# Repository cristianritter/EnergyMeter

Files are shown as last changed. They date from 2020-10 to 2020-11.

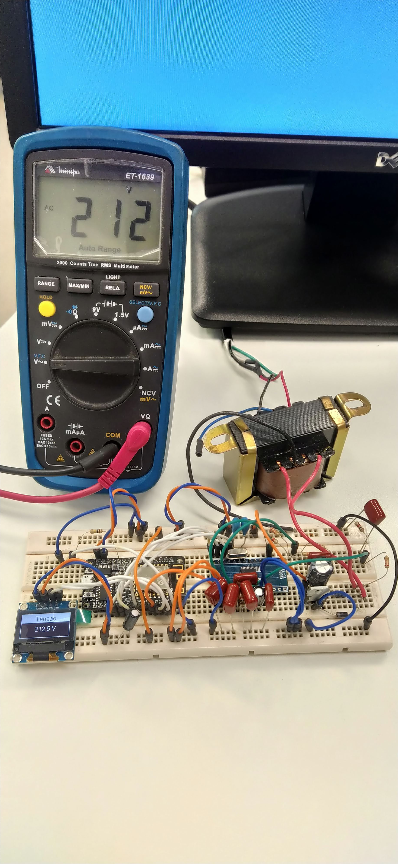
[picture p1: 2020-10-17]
DOCS/Medicoes/IMG_20200415_161844.jpg

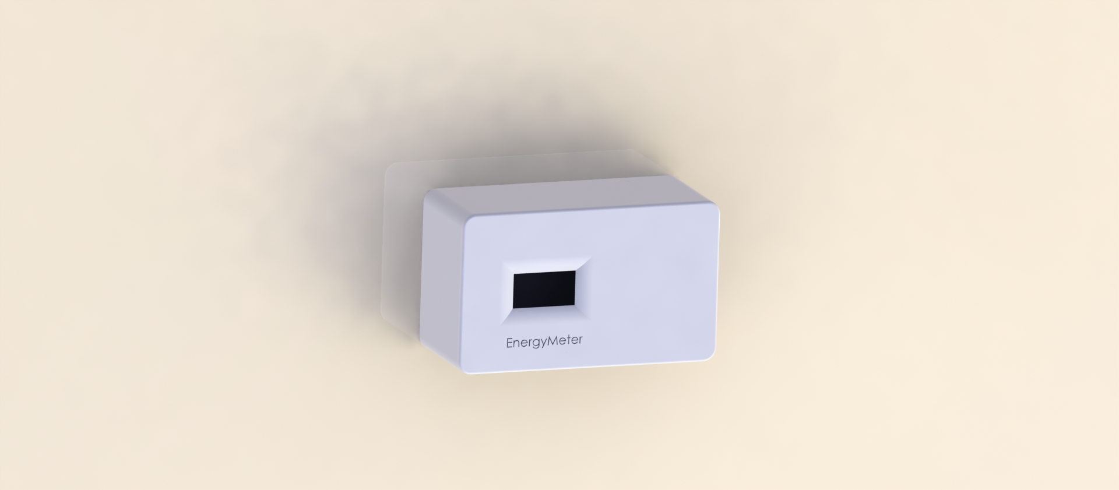
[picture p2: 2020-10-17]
DOCS/Ilustracoes/product_render.JPG

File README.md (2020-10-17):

# EnergyMeter

##### Este trabalho foi desenvolvido por Cristian Fernando Ritter para apresentação como Trabalho de Conclusão do curso de Engenharia Mecatrônica do IFSC.

O código do repositório foi embarcado em uma ESP8266 e possui um hardware externo de diversos componentes que executam as demais funções eletrônicas do conjunto.
Mais informações sobre o projeto podem ser encontradas na pasta DOCS.

>**Documentação disponível:**

| Pasta | Informações |
|---|---|
| DOCS  | Documentação do trabalho, artigos relacionados, datasheets e outras informações relevantes |
| ESP8266  | Código desenvolvido para o microcontrolador |
| Projeto  | Arquivos do projeto da placa de circuito impresso (Proteus) e dos invólucros (SolidWorks) |
| ServidorWeb  | Código da página web de consulta |

**Links Úteis**:

[Video da apresentação do TCC](https://drive.google.com/file/d/1ILbdENN5ZJW_IXzVvyy8BjTQIgMoMRp9/view?usp=sharing)

[Continuação do desenvolvimento com MariaDb e Mosquitto Broker rodando em uma rasp](https://github.com/cristianritter/ENERGY_METER_MOSQUITTO)

-----------
Este trabalho foi encerrado e a continuação do desenvolvimento está disponível no [link](https://github.com/cristianritter/ENERGY_METER_MOSQUITTO).

Florianópolis, Outubro de 2020.

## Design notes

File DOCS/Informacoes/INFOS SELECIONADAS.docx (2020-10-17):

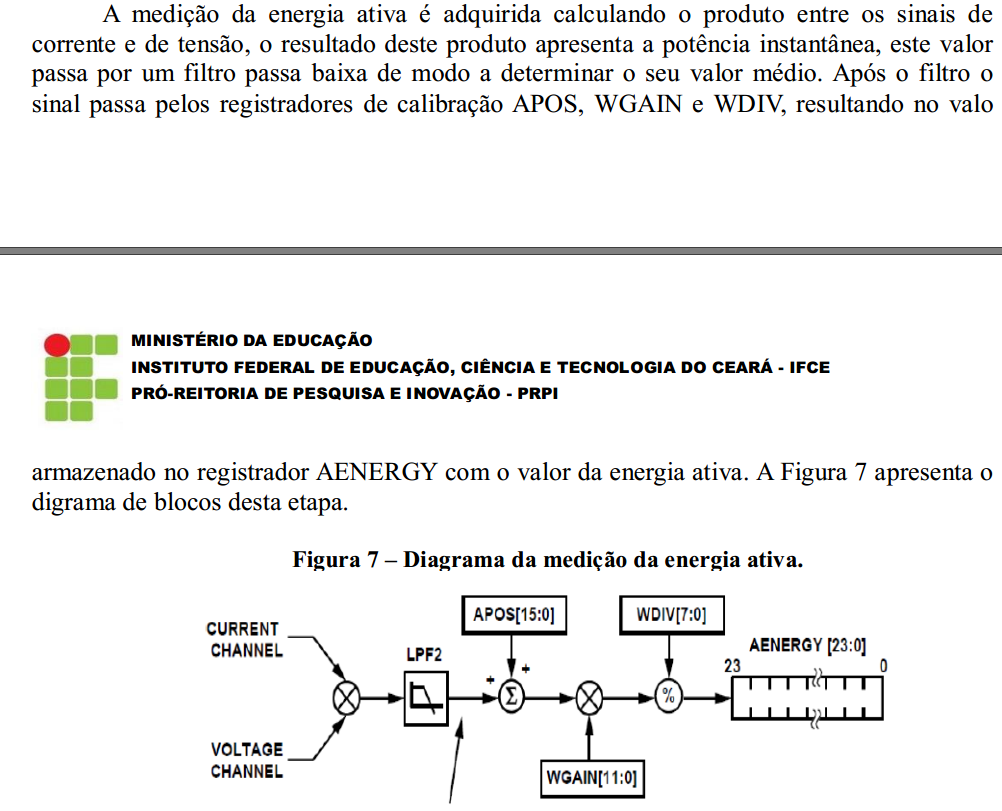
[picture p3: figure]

6. REFERÊNCIAS
ANEEL – Agência Nacional de Energia Elétrica. Informações técnicas: Tarifas,
consumidores Finais. Disponível em: <http://www.aneel.gov.br/area.cfm?idArea=91 >.
Acesso em: 07 mar. 2014.
ALEXANDER, C. K.; SADIKU, M. N. O. Fundamentos de circuitos elétricos. Porto
Alegre: Bookman, 2003.
ANALOG DEVICES, ADE7753 Data Sheet: Single-Phase Multifunction Metering IC
with di/dt Sensor Interface. 2017. Disponível em:
<http://www.analog.com/media/en/technical-documentation/data-sheets/ADE7753.pdf>.
Acesso em: 31 mar. 2017.
MINISTÉRIO DA EDUCAÇÃO
INSTITUTO FEDERAL DE EDUCAÇÃO, CIÊNCIA E TECNOLOGIA DO CEARÁ - IFCE
PRÓ-REITORIA DE PESQUISA E INOVAÇÃO - PRPI
BEN – Balanço Energético Nacional. Síntese do relatório final. Ano base: 2012. Rio de
janeiro: EPE, 2013.
BOYLESTAD, Robert L. Introdução à análise de circuitos. 12. ed. São Paulo: Pearson
Prentice Hall, 2012.
LEÃO, Ruth; Sampaio, Raimundo; ANTUNES, Fernando. Harmônicos em sistemas
elétricos. 1. Ed. Rio de Janeiro: Ed. Elsevier, 2014.
LEM. LV20-P Data Sheet: Voltage Transducer. 2005. Disponível em:
<http://media.digikey.com/pdf/Data%20Sheets/LEM%20USA%20PDFs/LV%2020-P.pdf>.
Acesso em: 03 mar. 2017.
______. LA55-P Data Sheet: Current Transducer. 2009. Disponível em:
<http://www.lem.com/docs/products/la%2055-p%20e.pdf>. Acesso em: 03 mar. 2017.
MARKUS, O. Circuitos elétricos: Corrente contínua e corrente alternada teoria e
exercícios. 9 ed. São Paulo: Érica, 2011.
NATIONAL INSTRUMENTS. O que é o LabView?. 2014. Disponível em:
<http://www.ni.com/newsletter/51141/pt/>. Acesso em: 31 mar. 2017.
POPSIN, J. Desenvolvimento de um analisador e medidor monofásico de energia.
Trabalho de conclusão de curso (Bacharel em Engenharia Elétrica), Universidade Luterana
do Brasil, Canoas - RS, 2010.

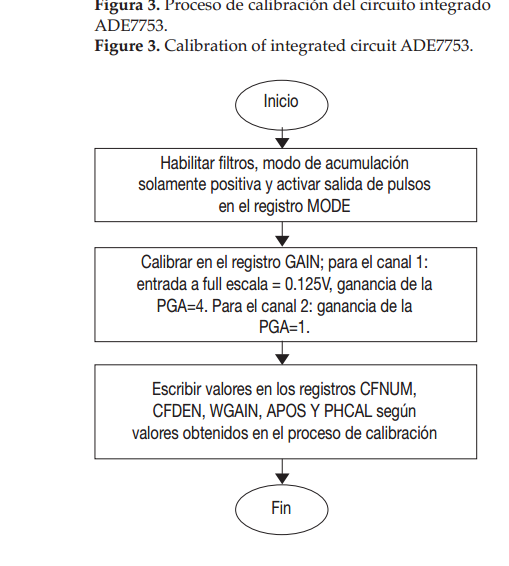
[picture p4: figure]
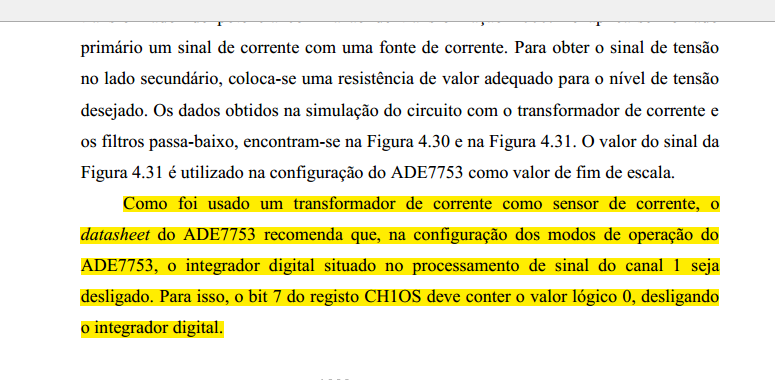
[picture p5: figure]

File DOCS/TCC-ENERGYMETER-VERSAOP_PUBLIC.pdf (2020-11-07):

CAMPUS FLORIANÓPOLIS

DEPARTAMENTO ACADÊMICO DE METAL-MECÂNICA

BACHARELADO EM ENGENHARIA MECATRÔNICA

CRISTIAN FERNANDO RITTER

## MEDIDOR DE ENERGIA MONOFÁSICO DE BAIXA TENSÃO

## BASEADO EM REDES SEM FIO

FLORIANÓPOLIS, OUTUBRO DE 2020

INSTITUTO FEDERAL DE EDUCAÇÃO, CIÊNCIA E TECNOLOGIA DE SANTA CATARINA

CAMPUS FLORIANÓPOLIS

DEPARTAMENTO ACADÊMICO DE METAL-MECÂNICA

BACHARELADO EM ENGENHARIA MECATRÔNICA

CRISTIAN FERNANDO RITTER

## MEDIDOR DE ENERGIA MONOFÁSICO DE BAIXA

## TENSÃO BASEADO EM REDES SEM FIO

FLORIANÓPOLIS, OUTUBRO DE 2020

Trabalho de Conclusão de Curso de Graduação,

apresentado à disciplina de Trabalho de Conclusão

de Curso, do curso de Engenharia Mecatrônica, do

Departamento Acadêmico de Metal-Mecânica, do

Instituto | Federal | de | Educação, | Ciência | e

Tecnologia de Santa Catarina, como requisito

parcial à obtenção do título de Bacharel em

Engenharia Mecatrônica.

Orientador Prof. Valdir Noll, Dr. Eng.

Ficha de identificação da obra elaborada pelo autor.

Ritter, Cristian Fernando
Medidor de Energia Monofásico de Baixa Tensão Baseado em Redes Sem Fio / Cristian Fernando Ritter ; orientação de Valdir Noll.
- Florianópolis, SC, 2020

86 p.

Trabalho de Conclusão de Curso (TCC) – Instituto Federal de Santa Catarina, Campus Florianópolis. Bacharelado em Engenharia Mecatrônica, Departamento Acadêmico de Metal Mecânica.

Inclui Referências.

1. | Internet | das | Coisas. | 2. | Monitor | de | Energia. | 3.
Microcontroladores. | I. | Noll, | Valdir. | II. | Instituto
Federal | de | Santa | Catarina. | Departamento | Acadêmico | de
Metal Mecânica. III. Título

MEDIDOR DE ENERGIA MONOFÁSICO DE BAIXA TENSÃO BASEADO EM REDES SEM

FIO

CRISTIAN FERNANDO RITTER

Este trabalho foi julgado adequado para obtenção de título de Bacharel em Engenharia

Mecatrônica e aprovado na sua forma final pela banca examinadora do Curso de Bacharelado em

Engenharia Mecatrônica do Instituto Federal de Educação, Ciência e Tecnologia de Santa Catarina.

Florianópolis, 16 de outubro de 2020.

Banca examinadora:

____________________________________

Prof. Valdir Noll, Dr.

Orientador

____________________________________

Prof. Gregory Chagas da Costa Gomes

Membro Titular

____________________________________

Prof. Mario de Noronha Neto, Dr.

Membro Titular

## RESUMO

RITTER, Cristian Fernando. MEDIDOR DE ENERGIA MONOFÁSICO DE BAIXA

TENSÃO BASEADO EM REDES SEM FIO. 85 f. Trabalho de Conclusão de Curso

(Graduação) – Curso de Engenharia Mecatrônica, Instituto Federal de Educação, Ciência e

Tecnologia de Santa Catarina. Florianópolis, 2020.

Neste trabalho propõe-se o desenvolvimento de um sistema para medição de energia

monofásico de baixa tensão baseado em redes de comunicação de dados sem fio que

realizará o monitoramento de diversos parâmetros elétricos da rede e seu registro em um

serviço de banco de dados. O sistema será desenvolvido em um microcontrolador que

enviará os dados para um serviço de Internet das Coisas. Uma interface web permitirá a

filtragem e consulta dos dados de qualquer lugar por meio de um acesso à internet. O banco

de informações adquirido poderá ser usado para inúmeros fins, que incluem: traçar um

padrão de consumo do local, definir estatisticamente a estimativa do consumo, verificar

informações relacionadas à conformidade do fornecimento de energia elétrica e possíveis

problemas na instalação elétrica, como desperdício de energia ou problemas no coeficiente

de fator de potência. Além disso, este sistema pode colaborar na realização de mudanças

nos hábitos de consumo que permitam aprimorar a eficiência energética do ambiente

monitorado.

Palavras chave: Internet das Coisas, monitor de energia, microcontroladores, sensores

de corrente e tensão.

## ABSTRACT

RITTER, Cristian Fernando. LOW-VOLTAGE SINGLE-PHASE POWER METER BASED

ON WIRELESS NETWORKS. 85 f. Trabalho de Conclusão de Curso (Graduação) – Curso de

Engenharia Mecatrônica, Instituto Federal de Educação, Ciência e Tecnologia de Santa

Catarina. Florianópolis, 2020.

This work proposes the development of a measuring single-phase low voltage energy

system based on a wireless network that will monitor several electrical grid parameters and

record them in a database service. This system will be developed in a microcontroller that will

use Internet of Things data. Web interface will allow filtering and querying data from anywhere

that has internet access. Collected database can be used for a number of purposes, which

include: drawing a consumption pattern, prediction, information related to the conformity of

the electricity and to investigate electrical installation troubles, such as waste of electricity and

problems with the power factor coefficient. In addition, this system can collaborate to make

changes in consumption habits allowing energy efficiency improvements.

Keywords: Internet of Things, energy monitor, microcontrollers, current and voltage

sensors.

## LISTA DE FIGURAS

Figura 18 – Diagrama de utilização de transformadores de corrente. Fonte: Analog Devices

Todas as figuras que não possuem fontes informadas são de autoria própria.

## LISTA DE EQUAÇÕES

## LISTA DE SIGLAS

ADC | Analogic to digital converter (conversor analógico-digital)
ABESCO | Associação Brasileira das Empresas de Serviços de Conservação de Energia
AC | Alternate Current (corrente alternada)
AGND | Analogic Ground (ground do circuito analógico)
AP | Access Point (ponto de acesso à rede sem fio)
AVDD | Tensão de alimentação positiva do circuito analógico
AWS | Amazon Web Services
CSS | Cascading Style Sheets
CT | Current Transformer (transformador de corrente)
DC | Direct Current (corrente continua)
DGND | Digital Ground (ground do circuito digital)
DVDD | Tensão de alimentação positiva do circuito digital
EC2 | Elastic Compute Cloud
GND | Ground
GPIO | General Purpose Input/Output
HTML | Hyper Text Markup Language
I2C | Inter-Integrated Circuit
IDE | Integrated Development Environment
IOT | Internet of things (internet das coisas)
JSON | Java Script Object Notation
LSB | Least Significant Bit (bit menos significativo)
MQTT | MQ Telemetry Transport
MSB | Most Significant Bit (bit mais significativo)
PHP | Hypertext Preprocessor
PWM | Pulse-Width Modulation
RMS | Root mean square

SLA | Service Level Agreement (termos do acordo de serviço)
SPI | Serial Peripheral Interface
TCP/IP | Internet protocol suite
UTC | Coordinated Universal Time
UTS | Unix Time Stamp

## SUMÁRIO

## 1 INTRODUÇÃO

Concorrentemente à popularização da internet e sua disponibilização sobre diversas

formas de propagação, muitas delas sem a necessidade de fios, houve também a ampliação

da gama de dispositivos com dimensões reduzidas e baixo consumo que podem acessar tais

redes e compartilhar dados de sensoriamento e até mesmo de controle para sistemas nas

mais diversas áreas, com uma ótima relação de custo benefício. Isso tem incentivado uma

cada vez mais evidente tendência de interconexão e monitoração de dispositivos e

ambientes, não somente industriais, mas também domésticos.

Diante da necessidade de coleta e análise de grandes quantidades de dados, surgiram

diversas empresas que oferecem serviços de tratamento e armazenamento de dados em

servidores remotos. Tais serviços dispensam a necessidade de quaisquer servidores ou

infraestrutura hospedada localmente para manter um serviço disponível online.

Dispondo do recente amadurecimento das tecnologias citadas acima, propõe-se neste

trabalho o desenvolvimento de um sistema para medição de energia monofásica de baixa

tensão baseado em rede sem fio que realizará o monitoramento e registro de diversos

parâmetros elétricos da rede. A medição dos parâmetros elétricos da rede será feita

utilizando um circuito integrado especificamente desenvolvido para este fim. Utilizar-se-á um

microcontrolador com interface de rede sem fio integrada para leitura, processamento e envio

de informações que serão armazenados em um serviço de armazenamento de dados online.

As análises e os resultados obtidos poderão ser consultados diretamente pela internet em

uma aplicação web desenvolvida para este fim.

Os dados obtidos poderão ser utilizados para diversos fins, como por exemplo, definir

estatisticamente a previsibilidade do consumo, verificar informações relacionadas à

conformidade do fornecimento de energia elétrica e possíveis mudanças nos hábitos de

consumo que permitam aprimorar a eficiência energética do ambiente monitorado.

### 1.1 OBJETIVOS

### 1.1.1 OBJETIVO GERAL

Desenvolvimento de um sistema que permita monitorar a qualidade de fornecimento e o

consumo de energia elétrica de uma residência ou outro ambiente. O sistema permitirá a

visualização dos dados em uma interface com gráficos de consumo em retrospecção, além

de análises baseadas nos hábitos de consumo registrados.

Os principais requisitos de projeto são:

- O hardware de aquisição dos dados deve ser compacto.
- O produto deve oferecer segurança ao usuário e fácil instalação.
- O custo do produto final deve ser um dos itens a ser considerado na escolha

dos componentes eletrônicos.

- O acesso do usuário à interface de consulta dos dados e resultados deve ser

feita de maneira simples e prática por meio de uma interface de aplicativo ou página

da web na internet.

- O dispositivo de medição deve ser capaz de enviar os dados para o banco de

dados por meio de redes sem fio.

- O acesso aos dados deve estar protegido de acessos indevidos por meio de

autenticação de usuário e senha ou outra tecnologia similar.

### 1.1.2 OBJETIVOS ESPECIFICOS

Para facilitar a organização deste trabalho e tentar garantir que todos os requisitos

citados no objetivo principal sejam atingidos com sucesso, foram elaborados objetivos

específicos que servirão como metas sequenciais a serem alcançadas durante o

desenvolvimento. Como itens de uma lista inicial de objetivos específicos podem ser

alistados:

- Descrição em esboço de funcionamento do sistema.
- Análise dos fluxos de dados e de viabilidade técnica e econômica.
- Pesquisa e definição das tecnologias e componentes a serem utilizadas.
- Estudo e descrição de todas as tecnologias e componentes envolvidos no

projeto.

- Elaboração dos diagramas elétricos e eletrônicos.

- Programação dos dispositivos eletrônicos e das plataformas de back-end.
- Execução de testes e correções.
- Programação das plataformas de front-end.
- Montagem de protótipo.
- Testes, correções e aprimoramentos finais.
- Apresentação dos resultados.

### 1.2 JUSTIFICATIVA

A utilização racional de energia é um ponto de pauta importante à medida que o mundo

procura pensar e agir de modo sustentável. Conforme relatório divulgado pela Associação

Brasileira das Empresas de Serviços de Conservação de Energia (ABESCO) e noticiado pelo

jornal O Estadão, o desperdício de energia custou mais de R$60 bilhões para a economia

brasileira nos anos de 2015 a 2017. Além do prejuízo econômico, o uso indiscriminado da

energia aumenta a geração de gases nocivos para a atmosfera, sendo responsável por uma

parcela no efeito.

No Brasil, a maior parte da geração de energia elétrica provém de usinas hidrelétricas,

ficando, portanto suscetíveis a mudanças climáticas e a períodos de estiagens, bem como

afeta o ambiente quando se necessita ampliar a produção, pois exigem grandes áreas

territoriais. Diante da ocorrência de longos períodos sem chuvas, outras formas de geração

de energia podem ser utilizadas, porém muitas delas geram maior poluição e possuem maior

custo por kWh gerado.

Para tentar analisar e corrigir os hábitos de consumo precisa-se mensurar

adequadamente o consumo de energia de modo adequado. Neste aspecto, o medidor de

energia elétrica da concessionária de energia não se mostra eficiente, pois não permite a

visualização remota nem a criação de um banco de dados retrospectivo de consumo, além

de não diferenciar os dados de cada ambiente.

A proposta deste trabalho é desenvolver um sistema capaz de facilitar a medição da

energia elétrica em residências ou ambientes similares, permitindo que sejam coletados

dados zoneados do consumo. Este sistema será capaz de informar quanto cada

equipamento está consumindo, e em quais horários.

Com um mapa de consumo completo do ambiente podem ser tomadas medidas

assertivas com o objetivo de substituir equipamentos de baixa eficiência energética e

identificar gargalos de consumo. Ampliando-se a utilização de um sistema como esse a nível

nacional, certamente poderiam ser minimizados o desperdício de energia e a necessidade de

constantes investimentos em infraestrutura de geração e distribuição de energia, além de

colaborar para um melhor uso dos recursos naturais.

### 1.3 METODOLOGIA

Conforme descrito nos objetivos, este projeto é um dispositivo de ‘Internet das Coisas’ e

utiliza plataformas de serviços disponibilizados online para evitar a necessidade de hospedar

servidores localmente. O sistema é formado por diversos serviços trabalhando em conjunto,

sendo cada um responsável por tarefas especificas.

Seu desenvolvimento tem caráter experimental, contemplando o projeto de um protótipo

de dispositivo para medição e a programação dos firmwares e códigos fontes das aplicações

necessárias. Além disso, será necessária a configuração de diversos serviços para a

integração dos componentes em nuvem computacional. O estudo necessário para o

desenvolvimento de tais atividades será realizado com base na documentação

disponibilizada pelos serviços web, documentações de bibliotecas, bem como também, na

informação presente nos manuais de componentes e em experiências de autores que

desenvolveram trabalhos semelhantes anteriormente.

Com a finalidade de facilitar o entendimento ao expor a integração esperada entre os

sistemas que serão desenvolvidos, será apresentado um esboço geral do sistema proposto.

### 1.3.1 ESBOÇO GERAL DO SISTEMA

A Figura 1 ilustra o relacionamento entre o conjunto dos serviços de computação em

nuvem, dos dispositivos de aquisição de dados e da interface com o usuário.

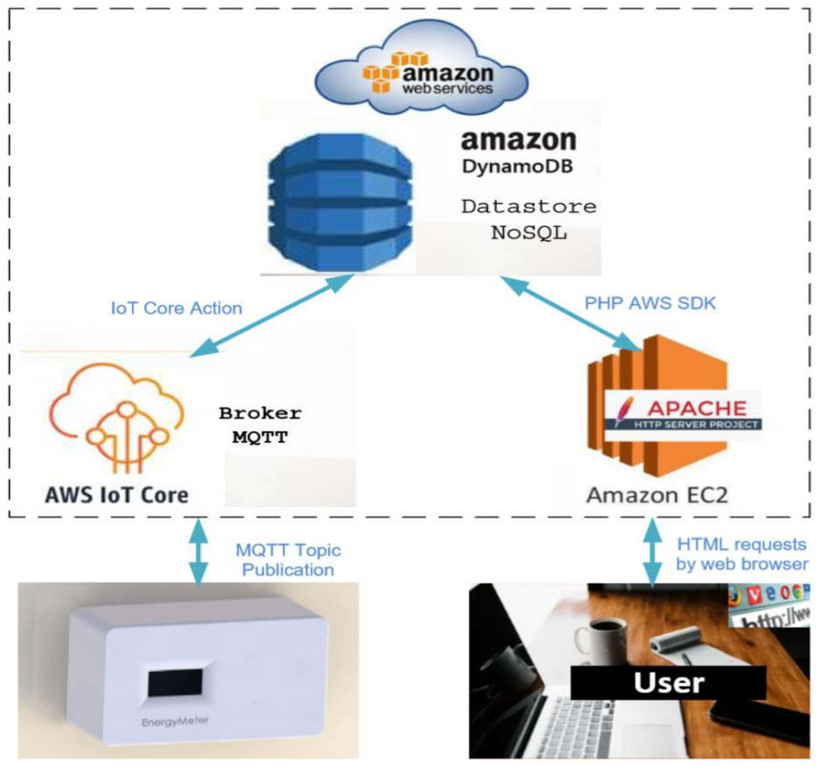
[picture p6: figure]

Figura 1 - Esboço geral do sistema.

Será produzido um protótipo de dispositivo eletrônico medidor de energia chamado de

Energy Meter, que executará o envio das informações adquiridas para um broker que

interpretará os dados e armazenará em um banco de dados online. Estes dados podem ser

consultados por meio de requisições realizadas de uma página web especificamente

desenvolvida para este fim que será disponibilizada por um serviço de hospedagem.

### 1.4 ESTRUTURA DO DOCUMENTO

A documentação deste projeto está dividida em capítulos para facilitar a organização,

sendo: Introdução, Fundamentação teórica, Desenvolvimento, Resultados e Conclusão.

Na Introdução estão contidas diversas informações iniciais, que incluem considerações

sobre o tema e o trabalho proposto. Nesta seção são definidos também os requisitos de

projeto, os objetivos e as razões que justificam o seu desenvolvimento.

A fundamentação teórica apresenta o estudo do conhecimento de base necessário para

a execução deste trabalho, com informações sobre todos os componentes, tecnologias,

linguagens de programação e formatos de dados utilizados. Todas as funcionalidades relevantes das plataformas serão explicadas, assim como seu funcionamento no presente

projeto. O embasamento do estudo das grandezas físicas mensuradas também estará

descrito nesta seção.

No Desenvolvimento estão descritas as razões que influenciaram a escolha dos

serviços e componentes escolhidos, e apresentados o circuito eletrônico e seu

funcionamento. São descritos os principais trechos de programação e as principais funções.

Na seção de Resultados apresentam-se um resumo e análises dos dados coletados

durantes os testes do protótipo produzido. Finalizando este capítulo são apresentadas as

principais dificuldades encontradas durante o desenvolvimento do trabalho.

A Conclusão apresenta observações relacionadas às expectativas com este projeto,

comentários oportunos sobre os objetivos que foram alcançados e sugestões de

aprimoramentos e desenvolvimentos para outros trabalhos.

## 2 FUNDAMENTAÇÃO TEÓRICA

### 2.1 SENSORES DE CORRENTE E TENSÃO

Serão utilizados sensores de tensão e corrente para a leitura dos parâmetros da rede.

O circuito integrado ADE7753 nos permite a utilização de diversos tipos de sensores.

Precisamos entender então a diferença entre eles para a seleção do sensor e sua correta

utilização.

### 2.1.1 SHUNTS RESISTIVOS

É composto basicamente por um resistor de baixo valor em série com a carga,

dimensionado de maneira que a queda de tensão seja bem pequena. Partindo-se do

princípio de que a queda de tensão é proporcional a corrente, pode-se mensurar a corrente

utilizando este tipo de sensor.

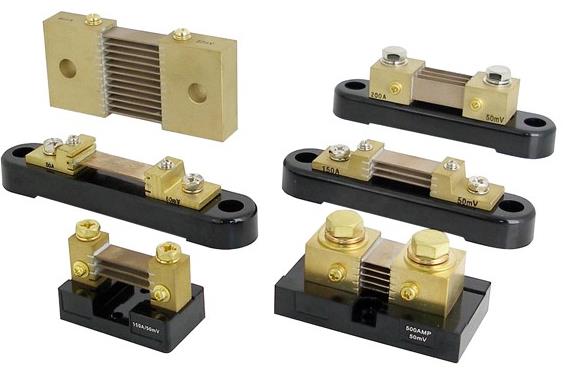
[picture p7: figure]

Figura 2 - Shunts resistivos. Fonte: AMDS4 (2020)

### 2.1.2 TRANSDUTORES DE EFEITO HALL

São dispositivos capazes de medir o fluxo de corrente com total isolamento galvânico,

isto é, sem a necessidade de inserir o dispositivo em série no circuito a ser medido. Podem

trabalhar com vários tipos de forma de onda e em uma ampla faixa de frequência. Possuem

uma saída em corrente determinada através de uma relação entrada / saída e possuem um

resistor de saída para transformar a saída de corrente em um valor de tensão. Pode-se

trabalhar com correntes alternadas ou contínuas, mas necessita de fonte de alimentação

auxiliar para o circuito hall.

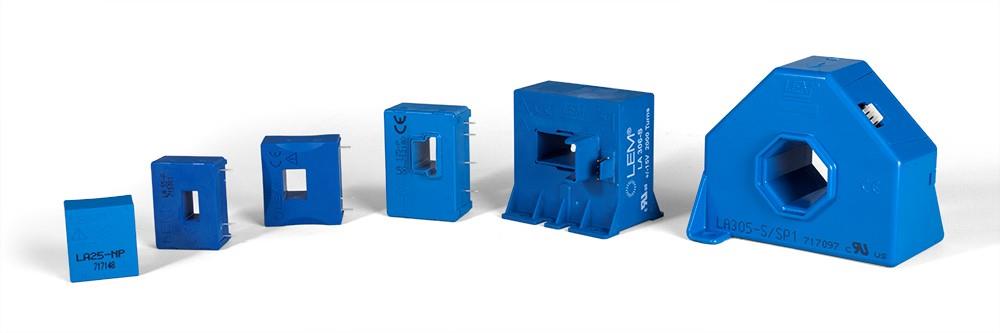
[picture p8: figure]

Figura 3 - Transdutores de Efeito Hall. Fonte: AMDS4 (2020)

### 2.1.3 TRANSFORMADOR DE CORRENTE

Um transformador de corrente [1] (conhecido como CT (Current Transformer)) é um

dispositivo que reproduz no seu circuito secundário, a corrente que circula em um

enrolamento primário com sua posição vetorial substancialmente mantida, em uma proporção definida, conhecida e adequada. É de baixo custo e serve apenas para correntes

alternadas.

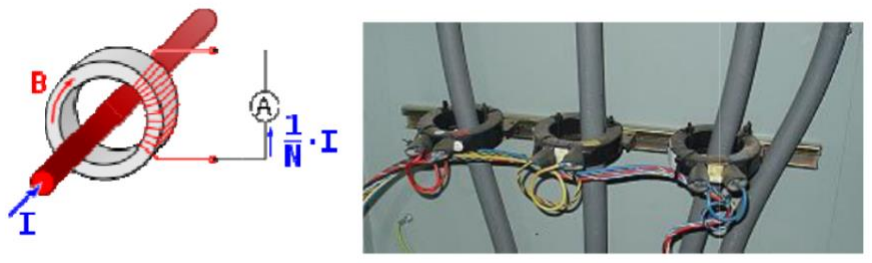
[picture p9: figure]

Figura 4 - Transformadores de Corrente. Fonte: AMDS4 (2020)

### 2.1.4 BOBINA DE ROGOWSKI

Na sua forma mais simples, a bobina de Rogowski é um sensor de corrente composto

por uma bobina enrolada uniformemente com muitas (N) voltas por metro em um núcleo não

magnético de área transversal constante. Por não possuir núcleo magnético, possui baixa

inércia eletromagnética, permitindo assim a medição de altas frequências com bastante

precisão. Serve apenas para correntes alternadas (AC).

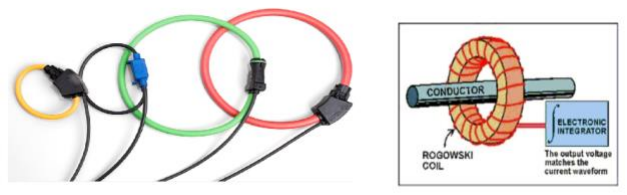
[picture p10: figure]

Figura 5 - Bobinas de Rogowski. Fonte: AMDS4 (2020)

### 2.1.5 ISOLAMENTO GALVÂNICO

Segundo a fornecedora YANASHI o isolamento galvânico em transdutores se faz

necessário quando se deseja que duas grandezas elétricas associadas fiquem separadas

eletricamente com o objetivo de atenuar interferências que possam causar danos ou

distúrbios aos circuitos ligados na saída do transdutor isolador. O isolamento colabora com a

segurança do circuito em casos de tensões altas, permitindo que a leitura do valor de

sensoriamento possa ser feita em uma tensão menor respeitando uma razão conhecida.

### 2.1.6 TRANFORMADOR E DIVISOR DE TENSÃO

Para o sensoriamento de tensões é comumente utilizado um circuito rebaixador

composto de dois resistores em série com uma derivação central. Através da relação entre a

resistência dos componentes utilizados obtêm-se uma amostra conhecida do valor de tensão

de entrada. Pode-se utilizar em conjunto com este circuito um transformador de tensão com

fator de redução conhecido para prover o isolamento elétrico.

### 2.2 CIRCUITO INTEGRADO ADE 7753

Este circuito integrado [6] mostrado na Figura 7 é um medidor que permite executar a

medição instantânea de potência ativa, reativa, e aparente em circuitos monofásicos de baixa

tensão. Permite também monitorar valores RMS de tensão e corrente, frequência, e de

eventos específicos como quedas de tensão e índices de fator de potência.

Figura 6 - Circuito integrado ADE7753. Fonte: Analog Devices (2010)

### 2.3 MÓDULO NODE MCU

O módulo de hardware conhecido como NodeMCU [3][4] é uma plataforma de

desenvolvimento que permite a prototipagem de projetos IOT. Os softwares utilizados são de código aberto (open source) e utilizam o microcontrolador Espressif ESP8266®
que integra

serviços de GPIO, PWM, I

2C e conversores A/D além de possuir também um módulo de

rede sem fio integrado que permite acesso à internet.

A parcela de serviços que será executada localmente está sob a responsabilidade

deste dispositivo. O módulo NodeMCU coletará as informações de energia dos registradores

do circuito integrado ADE7753 que está conectado aos sensores. Os dados adquiridos são

processados e publicados como uma mensagem JSON em um tópico MQTT previamente

definido.

Figura 7 - Módulo Node MCU com ESP8266. Fonte: FilipeFlop (2020)

### 2.4 PROTOCOLOS DE COMUNICAÇÃO E NOTAÇÃO

### 2.4.1 A INTERNET DAS COISAS E O PROTOCOLO MQTT

O protocolo MQTT é um protocolo com baixo payload (leve) de mensagens TCP/IP

para sensores ou dispositivos móveis. Este protocolo utiliza um esquema de comunicação

fundamentado no modelo publicador-assinante e é muito utilizado em internet das coisas.

Seu fundamento básico é apresentado na Figura 8.

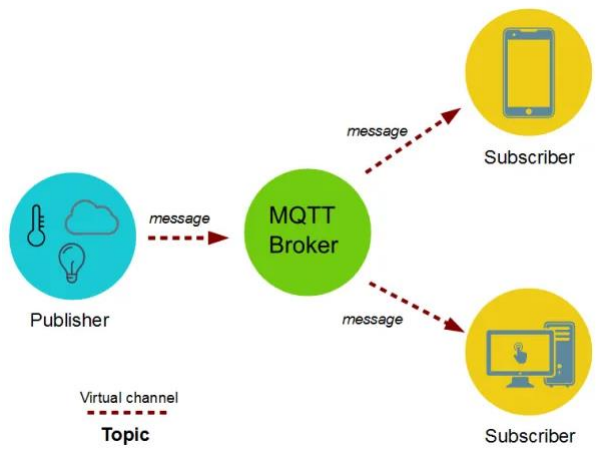
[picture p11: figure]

Figura 8 - Funcionamento do protocolo MQTT. Fonte: Ayush Gemini (2019)

São criados canais de comunicação virtuais chamados tópicos. Serviços e dispositivos

podem assinar ou publicar em um tópico de um broker específico. O tópico não faz parte da

mensagem, é apenas uma referência a um identificador de destino. Um dispositivo publica

em um tópico, e o broker MQTT realiza o envio da mensagem recebida a todos os

assinantes daquele tópico especifico.

A comunicação entre o dispositivo e o broker depende do serviço utilizado. Neste

trabalho utilizou-se o AWS IOT Core que se baseia em TCP/IP e transmite através da

internet executando autenticação de segurança por meio do uso de certificados.

### 2.4.2 SERIAL PERIPHERAL INTERFACE (SPI)

Este protocolo permite a comunicação do microcontrolador com diversos outros componentes, formando uma rede. É uma especificação de interface de comunicação série

síncrona usada para comunicação de curta distância, principalmente em sistemas

embarcados. No caso deste projeto a comunicação SPI permite que o modulo NodeMCU

execute a leitura e escrita dos registradores do circuito integrado ADE7743.

### 2.4.3 NOTAÇÃO JSON

Utilizaremos também um protocolo de notação muito comum para padronizar o

transporte de dados entre os serviços. O Java Script Object Notation (JSON) é um modelo de

formatação leve para troca de dados baseado em um subconjunto da linguagem de

programação Java Script e utiliza convenções familiares às linguagens C, Java, Java Script,

Perl, Python e muitas outras. Este modelo é constituído basicamente de uma coleção de

pares chave/valor. Em várias linguagens, isto é caracterizado como um dicionário ou matriz.

Estas são estruturas de dados universais e praticamente todas as linguagens de

programação modernas as suportam, sendo interessante que um formato de troca de dados

que seja independente de linguagem de programação se baseie nesse tipo de estrutura. A

Figura 9 apresenta um exemplo de pacote de dados JSON.

Figura 9 - Exemplo de pacote de dados JSON

### 2.5 AMAZON WEB SERVICES

A plataforma de serviços computacionais online Amazon Web Services (AWS) está

entre uma das mais adotadas e abrangentes do mundo, oferecendo mais de 175 serviços

disponíveis em qualquer lugar com acesso à internet. Milhões de clientes, incluindo

empresas de crescimento rápido (startups), grandes empresas e os maiores órgãos

governamentais, estão usando a AWS para reduzirem seus custos, ficarem mais ágeis e

inovarem seus processos mais rapidamente.

Neste projeto utilizam-se três serviços: o banco de dados Dynamo DB, o núcleo de

serviços de internet das coisas IOT Core e o serviço de computação em nuvem EC2.

Um guia explicativo sobre a configuração dos serviços AWS utilizados está disponível

no Apêndice B.

### 2.5.1 AWS IOT CORE

É um módulo da AWS que fornece serviços de IOT para soluções industriais,

comerciais e de consumo. O módulo AWS IOT Core permite que dispositivos conectados

interajam de maneira fácil e segura com aplicativos de nuvem e outros dispositivos.

Este serviço serve como um broker MQTT disponibilizando um canal de comunicação

entre o dispositivo e a nuvem computacional, permitindo a publicação em um tópico

específico, sendo assim responsável por receber as mensagens publicadas e retransmiti-las

a todos os clientes.

Neste projeto o tópico utilizado foi definido como: ‘aws/rules/Energy_meter’. A Figura 10

apresenta o formato da mensagem publicada.

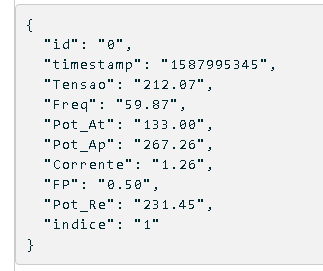
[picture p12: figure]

Figura 10 – Publicação de mensagem no tópico

A informação útil (payload) é uma matriz em um formato JSON. Os dados estão

organizados por chave e valor, permitindo que a mensagem seja interpretada pelo serviço

IOT Core. Pode-se configurar uma ação para que o próprio broker realize a interpretação dos

dados de cada mensagem e encaminhe o conteúdo para o banco de dados Dynamo DB.

Para que isso funcione deve-se certificar de que todas as colunas descritas nas chaves

existam de maneira idêntica no banco de dados Dynamo DB.

### 2.5.2 DYNAMO DB

É um serviço de banco de dados do tipo valor-chave que oferece ótimo desempenho e

confiabilidade dos dados armazenados. [9] Permite acesso aos dados por meio de diversas

linguagens computacionais, que incluem as mais utilizadas como Python, PHP e Java Script.

[10]

Neste projeto utiliza-se esta plataforma para armazenar as informações coletadas pelo

dispositivo de medição. Após a recepção de uma mensagem MQTT, seu conteúdo é

adicionado ao banco de dados pelo serviço IOT Core.

A Figura 8 mostra o formato de armazenamento de uma tabela do Dynamo DB. A

primeira linha define as chaves e as demais linhas representam os registros de valores.

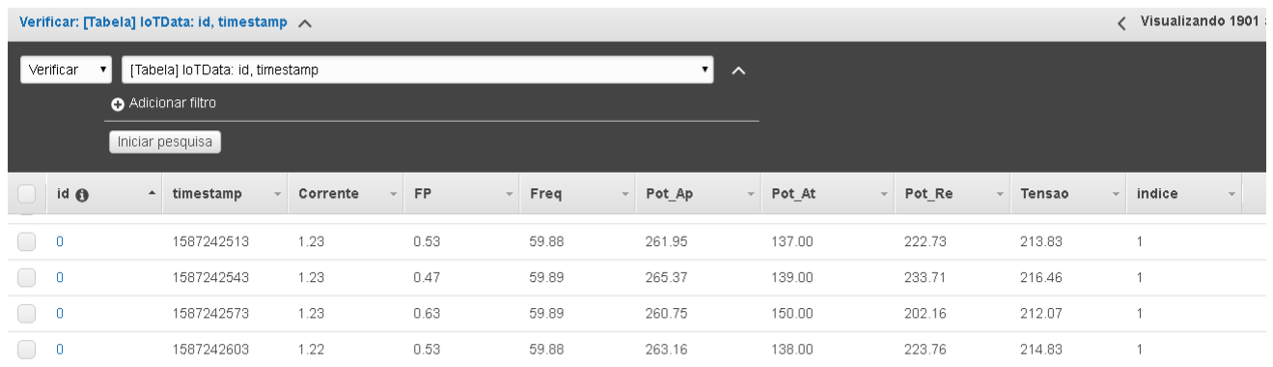
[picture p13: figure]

Figura 11 - Exemplo de tabela do Dynamo DB

Cada registro é formado por um conjunto de chaves e valores, sendo uma chave de

identificação do dispositivo, uma chave de classificação do registro e as demais chaves

relacionam os dados adquiridos. A chave id é chamada de chave de partição. A chave

timestamp, é uma chave de classificação e torna cada registro de dados único, por isso não

pode haver repetições dos valores desta chave. Isso é garantido pelo fato de que o valor de

timestamp é gerado no momento do envio do payload por um código UTS que corresponde à

quantidade de segundos desde o início do primeiro dia de janeiro 1970, no formato UTC +0.

### 2.5.3 AMAZON EC2

É um serviço que disponibiliza capacidade computacional segura e redimensionável na

nuvem computacional. Permite que seja configurado um sistema operacional em uma

máquina virtual e que serviços rodando nessa instancia sejam acessados remotamente de qualquer local. É possível liberar portas e acessos conforme a necessidade.

Utiliza-se esta plataforma para hospedar a aplicação desenvolvida, que será gerenciada

por um servidor Apache. Este servidor será responsável por responder a todas as

solicitações HTTP de consulta de dados. Far-se-á uso de uma instância executando o

sistema operacional Ubuntu Server e um servidor Apache. O acesso será realizado por meio

do endereço de DNS público da instancia EC2 por um navegador, tal como o Chrome.

### 2.5.4 PACOTE XAMPP

Adicionalmente aos serviços da Amazon, utiliza-se um pacote de softwares de uso livre

chamado XAMPP. Esta solução é uma distribuição Apache fácil de instalar e utilizar que contém os serviços de interpretação PHP, MySQL e Perl. É de uso livre, inclusive para fins

comerciais. Este serviço ficará hospedado em um servidor na nuvem e armazenará as

páginas web e os scripts PHP relacionados à consulta dos dados. Os demais serviços do

pacote não serão utilizados.

### 2.6 GRANDEZAS ELÉTRICAS

Para que possamos trabalhar corretamente com os sensores a serem utilizados,

precisamos entender os fundamentos relacionados às grandezas mensuradas. Neste projeto

usar-se-á a medição de sete grandezas diferentes, são elas: tensão, frequência, corrente,

potência ativa, potência reativa, potência aparente e fator de potência.

Grandezas como tensão, frequência, e corrente são corriqueiras e seus métodos de

medição bem compreendidos. O circuito integrado ADE7753 usado realiza a medição da

tensão por meio de um canal de entrada que mensura uma fração conhecida da tensão

amostrada. Posteriormente são realizados diversos cálculos para obtenção do valor real. A

frequência é obtida através da medição do período da onda amostrada, sabendo-se que a

frequência é o inverso do período da onda, pode-se calcular facilmente seu valor. A medição

de corrente neste caso será realizada por meio de um transformador de corrente, com

resistor de amostragem que transforma níveis de corrente dentro de um range específico em

níveis de tensão conhecidos com resposta linearizada, permitindo assim a medição de

corrente com uma exatidão aceitável.

### 2.6.1 POTÊNCIA APARENTE

É a soma vetorial das potências ativa e reativa. É medida em VA. Por meio desta

relação é extraído o valor do fator de potência de consumo da rede, que se resume ao

ângulo entre os catetos formados pelas potencias ativa e reativa. Este parâmetro da rede é

muito importante, pois está relacionado à eficiência do consumo excessivamente capacitivo

ou indutivo que, em alguns casos, pode ser mensurada e taxada pela empresa de

fornecimento de energia. Neste projeto o valor da potência aparente foi calculado por meio

da Equação 1.

S = VRMS.IRMS

Equação 1 - Potência aparente

### 2.6.2 FATOR DE POTÊNCIA

O fator de potência (FP) é uma relação entre a energia ativa e a energia aparente do

circuito em um determinado período de tempo. No ADE7753 temos dois registradores que

integram e armazenam cada um desses tipos de energia. Com duas amostras de períodos

distintos podemos calcular o FP. Se utilizássemos um período de 1 segundo entre a coleta

das amostras teríamos o apresentado na Equação 2. Este é o método utilizado para a

obtenção do fator de potência neste trabalho.

FP =

(EP1 − EP0

)

ES1 − Es0

=

P
S

Equação 2 - Fator de potência

### 2.6.3 POTENCIA ATIVA

A potência ativa instantânea é definida como a taxa de energia fluindo de uma fonte de alimentação para a carga a cada instante de tempo. É obtida pelo produto dos valores

instantâneos de tensão, corrente e fator de potência. A unidade de medida da potência ativa

é o Watt e equivale a um joule/segundo. A potência ativa está relacionada à realização de

trabalho como, por exemplo, geração de calor, movimento ou luz. A potência ativa é

calculada por meio da Equação 3.

P = V. I. cos θ = V. I. FP

Equação 3 - Potência ativa

### 2.6.4 POTÊNCIA REATIVA

É a energia utilizada que é responsável por manter o campo eletromagnético em

motores, geradores, transformadores e certos tipos de lâmpadas. Este tipo de energia não

gera trabalho, mas tem seu estudo relevante, pois afeta a carga das redes elétricas,

especialmente em grandes potências. Sua unidade de medida é o VAr. Neste trabalho seu

valor será obtido por meio da Equação 4.

Q = V.I. sen θ = V.I. sen(arc cos(FP))

Equação 4 - Potência reativa

## 3 DESENVOLVIMENTO

### 3.1 ELABORAÇÃO DO PROTÓTIPO

Para validar o projeto, o circuito eletrônico foi montado em uma placa de montagem

conforme mostra a Figura 12.

Figura 12 - Protótipo em placa de montagem

### 3.2 DESENVOLVIMENTO DA APLICAÇÃO WEB

Conforme as informações apresentadas na metodologia, os aspectos necessários de

configuração dos serviços WEB foram executados a contento. Os serviços da AWS foram

configurados e testados, a página web para interface com o usuário foi desenvolvida e

testada. A máquina virtual foi preparada, o servidor Apache instalado e os arquivos da

aplicação web carregados. Os procedimentos de configuração da AWS estão descritos no

apêndice B deste trabalho.

A aplicação web é composta de duas páginas: uma tela de autenticação, que é

apresentada na | Figura 13, e uma tela de dados, mostrada na | Figura 14.

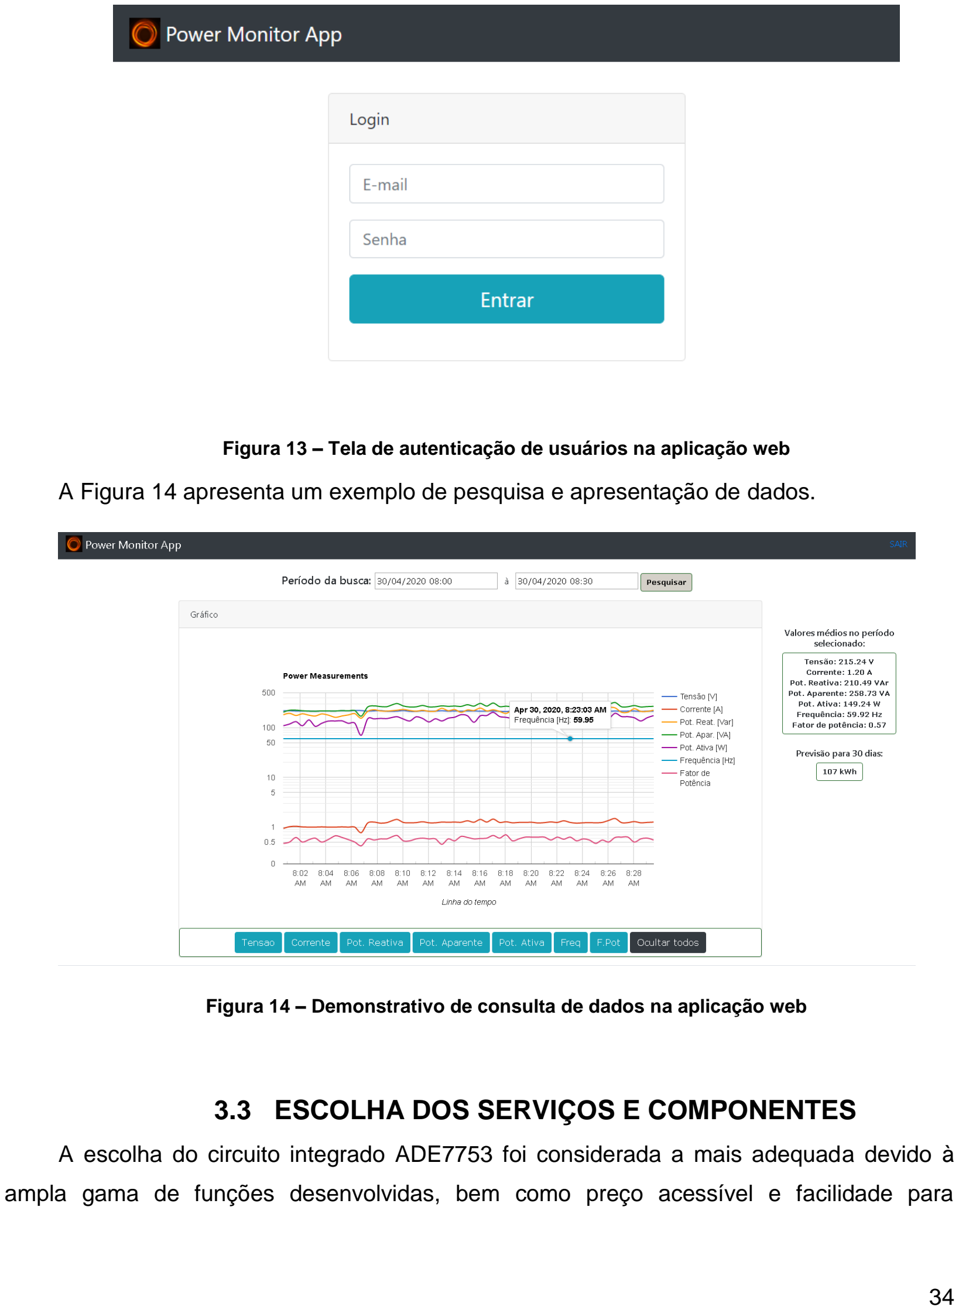
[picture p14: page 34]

Figura 13 – Tela de autenticação de usuários na aplicação web

A Figura 14 apresenta um exemplo de pesquisa e apresentação de dados.

Figura 14 – Demonstrativo de consulta de dados na aplicação web

### 3.3 ESCOLHA DOS SERVIÇOS E COMPONENTES

A escolha do circuito integrado ADE7753 foi considerada a mais adequada devido à

ampla gama de funções desenvolvidas, bem como preço acessível e facilidade para aquisição no mercado. Existem também, diversos trabalhos que utilizam este chip,

fornecendo uma ampla diversidade de materiais para consulta.

O microcontrolador ESP8266 foi escolhido para uso neste projeto pelo baixo custo e

adequação as necessidades do projeto. Seu tamanho físico reduzido com acesso à rede sem

fio incluído o tornam uma boa escolha para utilização em projetos de IOT.

A escolha da plataforma de serviços da Amazon foi uma escolha da equipe de projeto.

Existem diversos trabalhos que utilizam outras plataformas, principalmente com servidores

hospedados localmente, como por exemplo, utilizando o Mosquitto MQTT Broker e a SQL

database. Os serviços da AWS se encaixaram neste projeto, pois ainda não existem muitos

trabalhos acadêmicos que façam uso desta plataforma, além de ser um serviço comercial

cujo aprendizado pode ser útil posteriormente. A configuração dos serviços desta plataforma

não é de trivial aprendizado, mas está muito bem documentada. Além da documentação do

fabricante, existem também tutoriais em vídeos na plataforma Youtube que também auxiliam

no aprendizado desta plataforma. Todos os materiais utilizados estão alistados na bibliografia

deste trabalho.

O modelo de sistema apresentado com todos os serviços hospedados em servidores de

terceiros, possui diversas vantagens, como por exemplo, não existe a necessidade de dar

manutenções regulares, nem ter uma equipe local de suporte, diminuindo as despesas com

esses aspectos. A confiabilidade do serviço é aprimorada, sendo que a AWS promete uma

disponibilidade SLA (Service Level Agreement) de 99,99% no serviço de cloud computing. As

despesas por estes serviços são fixas e definidas pelas cotas de uso. Apesar disso,

dependendo da aplicação, pode ser vantajoso manter um serviço hospedado localmente, que

não dependa de serviços web contratados. Atualmente o valor de um contrato simples de computação em nuvem com a AWS está custando aproximadamente $100 por mês. Então

se não necessitamos de tanta confiabilidade quanto é oferecida pela AWS, pode ser

vantajoso testar provedores mais baratos deste serviço.

Trazendo a atenção para as linguagens de programação utilizadas, foram escolhidas

linguagens que estão sendo muito usadas no mercado. A programação da ESP8266 foi

desenvolvida em C, sendo a linguagem de mais baixo nível que compõe este trabalho. Todas

as demais estão relacionadas à programação web, que podem englobar muitas linguagens

em um mesmo sistema. A página web criada neste projeto utilizou trechos de código em

HTML, PHP, CSS e Java Script, além de utilizar pacotes de terceiros, como por exemplo, o

BOOTSTRAP que traz recursos de design importantes para a plataforma web. Várias

empresas disponibilizam | SDKs (Software development kit). | para utilização dos

desenvolvedores e isto é muito útil, pois permite que trechos de códigos já prontos sejam

reutilizados, facilitando o desenvolvimento. [18]

### 3.4 CIRCUITO ELETRÔNICO

Na Figura 15 é apresentado o circuito eletrônico do dispositivo proposto. O arranjo dos

componentes foi elaborado através das sugestões dadas pelo fabricante no manual do

componente.

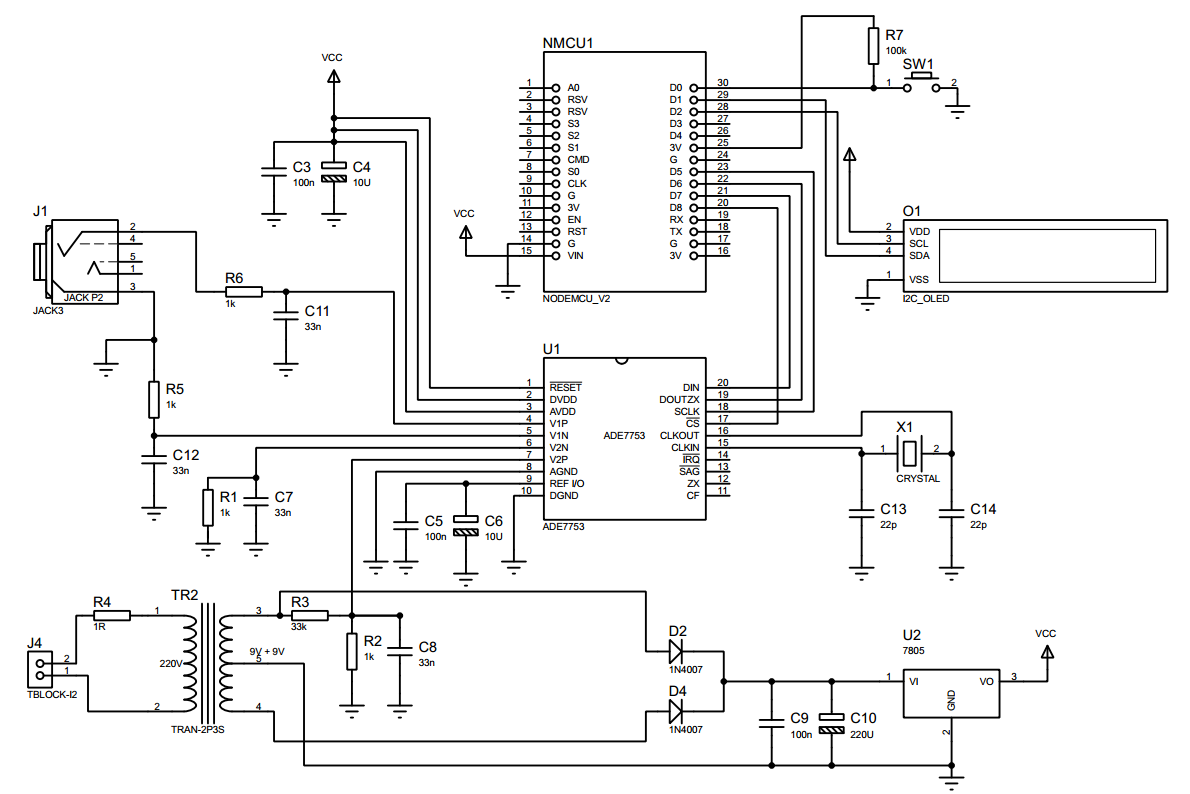
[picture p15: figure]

Figura 15 - Diagrama do circuito elétrico

O funcionamento deste circuito está construído sobre dois pilares principais. O primeiro

pilar está no circuito integrado ADE7753, que é um medidor de energia monofásico da

Analog Devices. O segundo pilar é composto pelo microcontrolador ESP8266 que faz parte

do módulo NodeMCU.

O circuito integrado executa todas as tarefas relacionadas à interpretação dos valores

retornados pelos sensores que a ele estão conectados, extraindo os valores desejados de

potências, tensão, corrente, entre outros. Todos estes valores estão armazenados em

registradores que podem ser lidos por meio do protocolo de comunicação SPI. Nos próximos

itens descreve-se em detalhes cada um desses pilares.

### 3.4.1 MEDIÇÃO DE ENERGIA COM O ADE7753

As conexões elétricas deste circuito integrado foram executadas conforme instruções

do fabricante presentes no datasheet do produto. A seguir então descritas às informações

sobre os principais pinos utilizados e suas funções especificas:

a) Os primeiro três pinos são respectivamente o pino de reset, a alimentação positiva

do circuito digital (DVDD) e a alimentação positiva do circuito analógico (AVDD).

Sendo o reset ativo em nível lógico baixo, manteremos estes três pinos conectados

ao VCC.

b) Pinos 8 e 10 são pinos complementares de alimentação, respectivamente AGND

(Analogic Ground) e DGND (Digital Ground) que devem ser conectados ao GND.

c) O pino 9 é uma referência interna que o fabricante recomenda que seja desacoplada

do AGND utilizando dois capacitores conforme apresentado no diagrama.

d) Pinos 15 e 16 são os pinos de CLKIN e CLKOUT, conectados a um cristal oscilador

de 3.57MHz que fornece o clock de funcionamento do circuito.

e) Pinos 17 a 20 são os pinos da comunicação serial, são conectados aos pinos de

comunicação SPI do módulo Node MCU.

f) Os pinos 6 e 7 são as entradas analógicas do canal 2 e devem ser utilizadas com

um transdutor de tensão. Neste projeto faremos uso de um divisor de tensão

resistivo acoplado a um dos enrolamentos do transformador de entrada de rede para

obter uma amostra do valor de tensão.

g) Os pinos 4 e 5 são as entradas analógicas diferenciais do canal 1 e são

desenvolvidas para serem utilizadas em conjunto com um sensor de corrente. Estão

conectadas a um conector TRS 3.5mm fêmea para utilização com o sensor de

corrente.

Os registradores e principais protocolos utilizados para a comunicação entre este

circuito integrado e o módulo Node MCU serão explanados posteriormente na seção

sobre o software.

### 3.4.2 TRANSFORMADOR DE CORRENTE

Para aquisição dos dados de corrente usa-se o CT modelo SCT-013-020 conforme

mostra a Figura 16. Segundo informações do fabricante, este sensor apresenta 3% de erro

em fundo de escala, considerado aceitável pela equipe de projeto.

Figura 16 - Transformador de Corrente SCT-013-020. Fonte: Nice gear (2020)

### 3.4.3 FONTE DE ALIMENTAÇÃO

Na Figura 17 pode-se ver o circuito responsável pela alimentação do sistema.

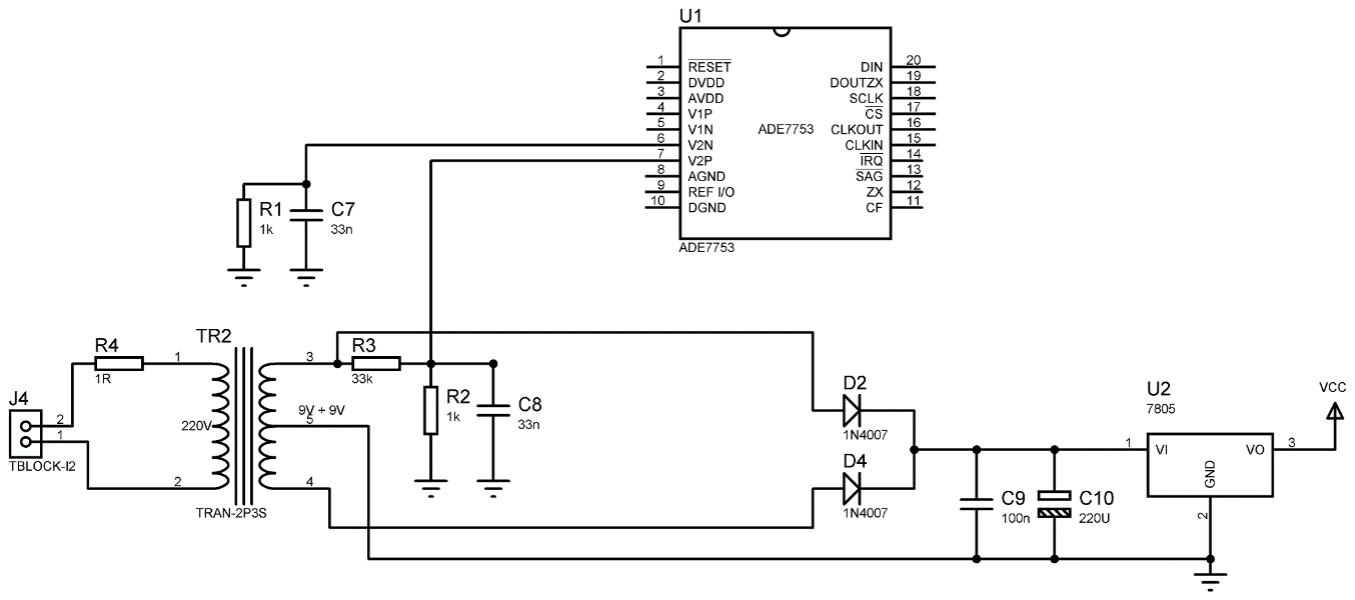
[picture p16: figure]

Figura 17 - Circuito de alimentação e canal 2 de Tensão

O conector J4 está conectado a entrada da rede AC em 220V. O resistor R4 atua como

proteção do sistema em caso de curto circuito ou sobre corrente. TR2 é um transformador

com derivação central de 9V + 9V que é retificada em um modelo de onda completa com

dois diodos. Após a filtragem existe um regulador de tensão que estabiliza a tensão de saída

VCC em 5V.

### 3.4.4 CANAL 2 – SONDA DE TENSÃO

Na Figura 14 é apresentado também o amostrador de tensão que está conectado ao

canal 2 do ADE7753. Enquanto o pino V2N está conectado ao GND por meio de R1 e C7, o

pino V2P está conectado ao divisor de tensão formado por R3 e R2. Sendo a tensão eficaz

sobre R3 + R2 de 9V, podemos calcular a tensão de pico utilizando a Equação 5.

VRMS = 0,707 ∗ Vp

Equação 5 - Equação tensão de pico

Logo, a tensão de pico-a-pico (Vp) sobre R3 +R2 será de:

V(R3 + R2)p =

±9V
0,707 = ±12,73

Equação 6 - Calculo da tensão de pico no canal 2

A derivação central deste divisor de tensão fornece o valor para a amostragem no

circuito integrado ADE7753. Conforme informações do fabricante, o valor de amostragem na

entrada diferencial do circuito integrado deve estar entre +-0,5V. Para isso precisamos que a

tensão sobre R2 esteja dentro deste intervalo.

Verificamos isso utilizando a equação para divisores de tensão. Para R3 = 33k e R2 =

1K temos:

VR2p =

(VR3p + VR2p) ∗ R2
(R3 + R2)

=

±12,73 ∗ 1k
34k = ±0,374Vp

Equação 7 - Calculo da tensão diferencial no canal 2

Obtendo-se esse valor de 0,374V para uma tensão de pico de 12,73V no transformador

podemos elaborar uma relação para referenciar o valor da tensão da rede conforme as

equações abaixo:

VRMS(rede) = Vp(rede) ∗ 0,707

Vp(rede) = Vp(primario)

Vp(primario) = Vp(secundario) ∗ (fator de reducao do transformador medido indiretamente)

= Vp(secundario) ∗ (

217.3
8.11 )

Vp(secundario) = VR2p ∗ (

12,73
0,374)

Substituindo as equações temos que:

VRMS = VR2p ∗ (

12,73
0,374) ∗ (

217.3
8.11 ) ∗ 0,707

VRMS = VR2p ∗ 644,22

Equação 8 - Cálculo do fator de multiplicação para calibração

Assim podemos utilizar o valor mensurado pelo canal 2 para estimar a tensão da rede.

### 3.4.5 MEDIÇÃO DE CORRENTE

O canal 1 será utilizado com um sensor do tipo transformador de corrente modelo SCT-

013-020. Conforme as informações do fabricante, este sensor permite a leitura de correntes

em uma faixa de 0 a 20A. Este sensor possui internamente um resistor de amostragem que

gera um sinal de 0 a 1V na saída com erro de linearidade de 3%.

Instruções do fabricante orientam a instalação de um transformador de corrente

conforme o modelo apresentado na Figura 18.

Figura 18 – Diagrama de utilização de transformadores de corrente. Fonte: Analog Devices (2010)

Neste projeto intentou-se a alteração do diagrama original pela adição de um divisor

resistivo para que a tensão sobre a entrada diferencial não ultrapasse os 0,5V descritos no manual do fabricante, visto que o sensor utilizado apresenta tensão de 0-1V para um range

de corrente entre 0-20A. Como resultado prévio cita-se que esta configuração com divisor de

tensão causou a depreciação do funcionamento e impedindo a medição. Para resolver o

problema utilizou-se o sistema exatamente como descrito pelo fabricante, ficando a corrente

de medição restrita a 0-10A para conformidade do range de entrada do circuito integrado. O

diagrama final é apresentado na Figura 19.

Figura 19 - Configuração de entrada do Canal 1 de Corrente

Para este canal segue-se o mesmo modelo de cálculo utilizado no canal 1.

Temos um intervalo de saída em tensão sobre o resistor de amostragem interno ao

sensor que retorna valores de 0 a 1V para correntes respectivamente de 0 a 20A.

Utilizaremos um range máximo de 10A que garante o valor para 0,5V na entrada do canal 1.

Logo temos a seguinte equação:

I = V ∗ (

10
0,5

) = V ∗ 20

Equação 9 - Cálculo de valor de corrente no canal 1

### 3.4.6 DISPLAY OLED

Figura 20 - Display OLED SSD1306. Fonte: ETT (2020)

A Figura 21 apresenta a conexão do display OLED (organic light-emitting diode) ao

microcontrolador ESP8266.

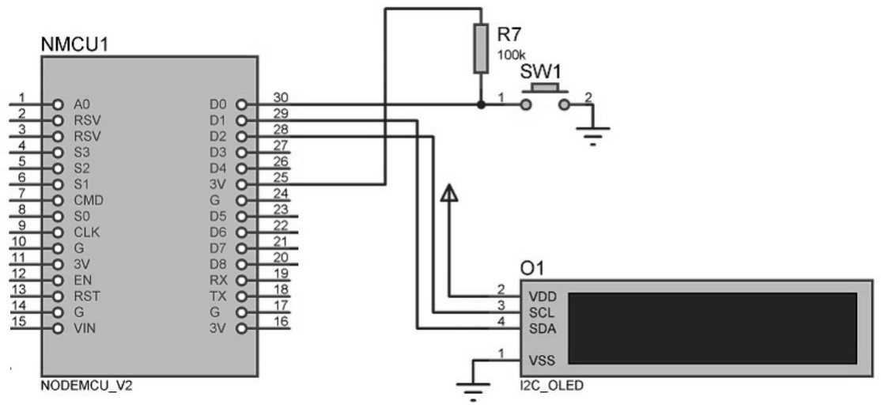
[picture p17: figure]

Figura 21 - Conexão do display OLED ao microcontrolador

Conectado aos pinos D1 e D2 do módulo Node MCU temos os pinos da comunicação

I2C (Inter-Integrated Circuit) do display. Esta tela apresentará algumas informações do

dispositivo, como o status e estabilidade da conexão com a internet e informações dos dados

coletados da rede elétrica. Através da chave SW1 podemos fazer a mudança entre as

informações apresentadas na tela. A Figura 22 apresenta a descrição das possíveis

informações do display.

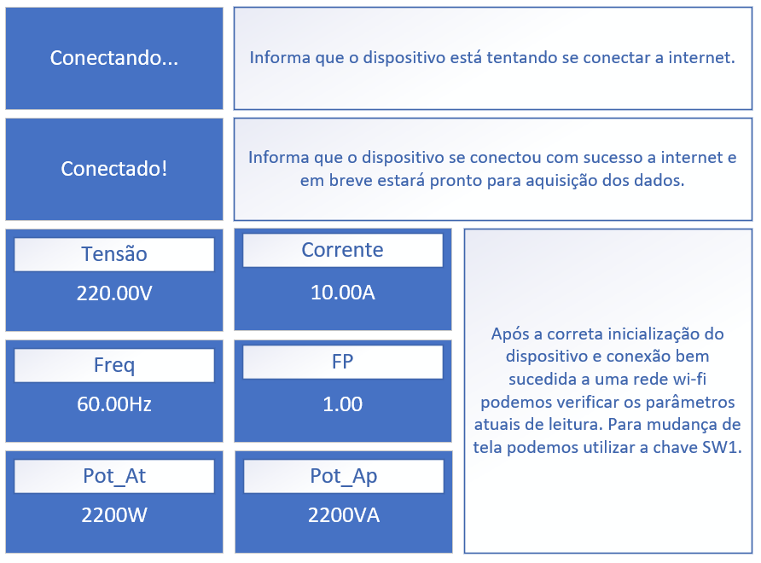
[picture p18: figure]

Figura 22 - Informações do display

### 3.5 DESIGN DE PCI E INVÓLUCRO DE POLÍMERO

Para a montagem definitiva do protótipo que permitiria sua utilização profissional em um

ambiente real, foi projetado um case de polímero conforme apresentado na Figura 23. Neste

involucro estarão conectados um plugue elétrico macho para conexão a energia elétrica de

alimentação do sistema e um plugue fêmea do tipo P2 para a conexão do sensor de corrente

que deve ser conectado ao condutor fase da instalação a ser monitorada.

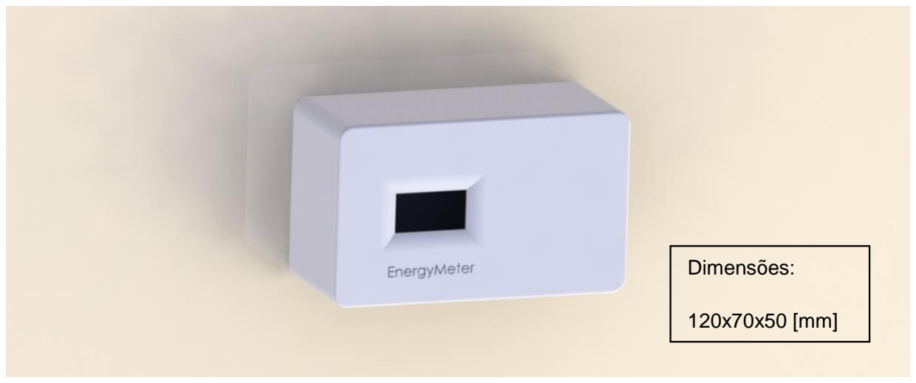
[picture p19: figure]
Dimensões:

Figura 23 – Projeto de invólucro para o dispositivo

Foi projetada também uma placa de circuito impresso para alocação definitiva dos

diversos componentes. A face superior da placa é apresentada na Figura 24.

Figura 24 – Máscara de componentes da placa de circuito impresso

A face inferior da placa projetada é apresentada na Figura 25.

Figura 25 – Máscara inferior da placa de circuito impresso.

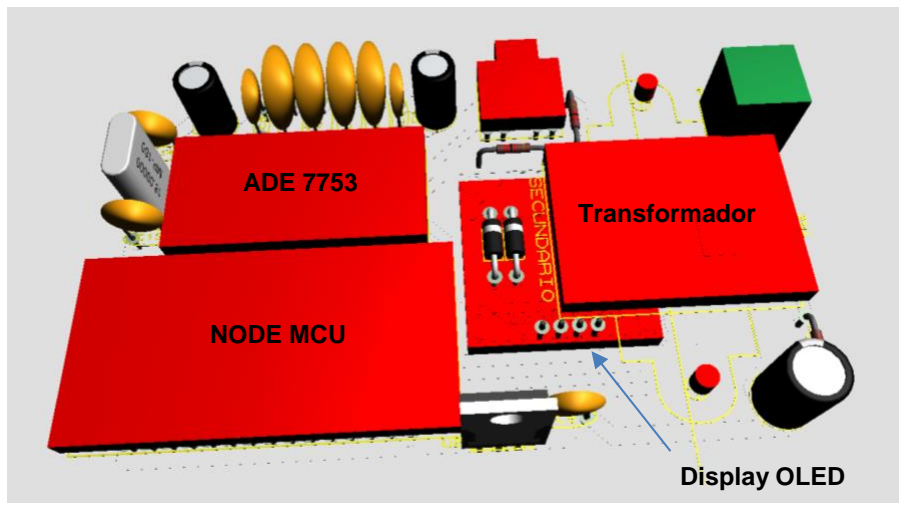
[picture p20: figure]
Transformador; NODE MCU; ADE 7753; Display OLED

Figura 26 - Vista 3D da placa

Como pode-se notar na Figura 26, o display de OLED fica localizado na face inferior

da placa, enquanto os demais componentes se encontram na face superior. Isso permite o

encaixe no invólucro projetado.

Os componentes NodeMCU e ADE7753 estarão soldados sobre suportes do tipo

soquete elevados da placa, o que permite que existam componentes soldados na parte

inferior da mesma face. Isso permite que o projeto seja executado em uma PCI de face

simples e facilita a fabricação do mesmo com a estrutura disponível no instituto.

### 3.6 SOFTWARES DESENVOLVIDOS

O software do sistema proposto está dividida em três partes principais: programação do

módulo NodeMCU com o microcontrolador ESP8266 [4][5], a programação da interface web

e a configuração dos diversos serviços AWS.

A Figura 27 mostra um fluxograma do funcionamento do sistema de software.

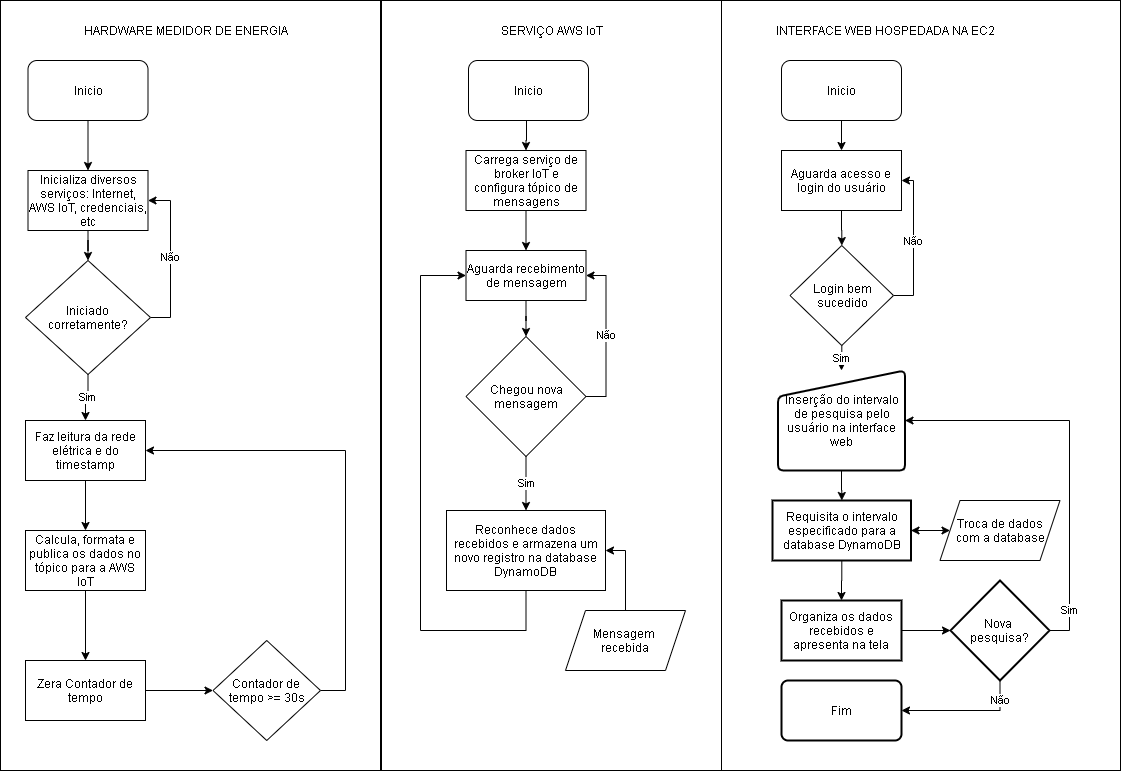
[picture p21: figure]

Figura 27 - Fluxograma do funcionamento do software

### 3.6.1 CIRCUITO INTEGRADO ADE 7753

Durante a inicialização sistema, é necessária que seja feita a configuração do modo

de operação do ADE7753. Tais informações ficam armazenadas em memória volátil, logo

precisa ser refeita a cada reinicialização. Para isso existem endereços de memória

específicos chamados de registradores. Os métodos de leitura e gravação estão descritos na

próxima seção deste trabalho. Existem também registradores utilizados para leitura dos

dados mensurados pelo circuito integrado.

Na Tabela 1 destacamos os principais registradores utilizados neste trabalho e suas

respectivas funções.

Nome | Endereço de memória | Função
0x02 | AENERGY | Leitura dos valores registrados de energia ativa
0x05 | VAENERGY | Leitura dos valores registrados de energia aparente
0x09 | MODE | Escrita de diversos bits que configuram a operação do circuito
0x0B | STATUS | Leitura de diversas interrupções que podem ser configuradas, como por exemplo, tensão baixa, sobre tensão, temperatura, entre outros.
0x16 | IRMS | Leitura do registrador de medição de corrente
0x17 | VRMS | Leitura do registrador de medição de tensão
0x0D | CH1OS | Escrita da configuração de offset do canal 1
0x0E | CH2OS | Escrita da configuração de offset do canal 2
0x1C | LINECYC | Escrita da configuração de quantidade de ciclos de integração para medição de potência

Tabela 1 – Principais registradores do ADE 7753

### 3.6.2 MÓDULO NodeMCU

Dentre as funções deste módulo atrelado ao microcontrolador, estão incluídas: acesso

à internet por meio de uma conexão sem fio, escrita e leitura dos registradores do circuito

integrado ADE7753, processamento das informações recebidas e posteriormente o envio de

dados para a nuvem computacional. Esses dados são enviados por meio do protocolo MQTT

contendo todos os dados para o tópico do broker AWS.

Para programação das diversas funções descritas utiliza-se uma biblioteca chamada

ESP8266.h disponível no GitHub. [7] Todos os links para os arquivos utilizados estão

disponíveis nas referências bibliográficas deste trabalho. [17] Conforme as instruções da biblioteca, usar-se-á a IDE Arduino para a programação. Todos os aspectos relacionados à

instalação estão descritos no arquivo README da biblioteca.

O código fonte completo e comentado está disponível para consulta no GitHub

(https://github.com/cristianritter/EnergyMeter). Este foi dividido em seis arquivos para facilitar

a organização e compreensão. E estrutura ficou definida como se apresenta na Figura 28.

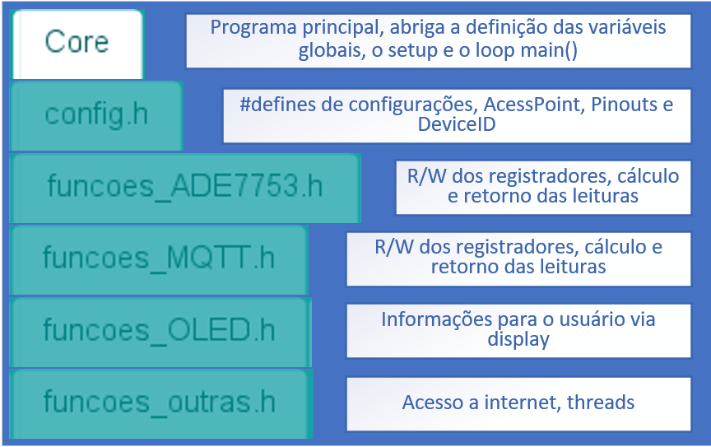
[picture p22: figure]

Figura 28 - Descrição da programação do microcontrolador

Os principais trechos do código são descritos a seguir.

A configuração da rede sem fio é feita conforme o código apresentado na Figura 29.

Figura 29 - Configuração da rede wi-fi

A Figura 30 apresenta a configuração do nome do dispositivo que é utilizada para

identificação de uma thing na tabela de dados. Podemos ter inúmeros dispositivos gravando

dados paralelamente na mesma database, contanto que esta função seja implementada no

futuro.

Figura 30 - Configuração de identificação de dispositivo

O tempo entre uploads pode ser configurado dependendo da periodicidade desejada.

Cada registro possui um valor de cada parâmetro mensurado.

Figura 31 - Configuração de periodicidade

No arquivo funções_MQTT.h são definidos os endereços de hosts do dispositivo na

AWS e os certificados de segurança necessários para autenticação do dispositivo. Estes

certificados são gerados durante a criação de uma thing e serão descritos posteriormente.

Figura 32 - Configuração de certificados

O Circuito integrado ADE7753 possui vários registradores que podem ser lidos ou

escritos conforme a necessidade. Antes de estar pronto para ler os parâmetros da rede,

precisamos configurar alguns parâmetros de modo de operação, offsets e ganhos. Isso é

feito por meio da escrita em registradores específicos. A função configADE() executa estas

configurações por gravar os valores definidos de cada registrador.

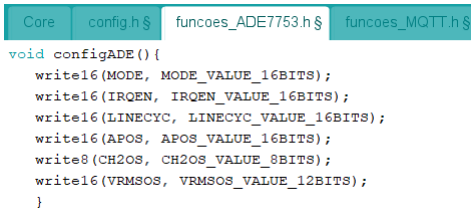
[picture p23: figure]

Figura 33 - Configuração dos registradores do ADE7753

O método de escrita nos registradores é descrito na função a seguir. Primeiramente

habilita-se a comunicação SPI utilizando a função enableChip(). O parâmetro reg carrega o endereço do registrador que é sempre um valor de oito bits com o bit mais significativo (MSB)

nulo. Para indicar ao chip que desejamos realizar uma escrita, devemos enviar o endereço

do Registrador que deve ser escrito com o bit MSB ligado. Isso é feito utilizando a função

(endereço do registrador | 0b1000000). Respeitando os tempos de atraso descritos no

datasheet podemos enviar os dados que correspondem aos valores a serem gravados no

registrador e enfim finalizar a comunicação. Deve-se respeitar o tamanho do registrador de

destino, neste caso foi enviado um valor de 16 bits.

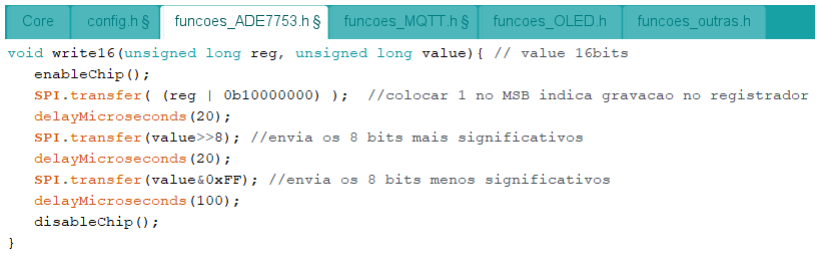
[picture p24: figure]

Figura 34 - Método de escrita nos registradores

A leitura dos registradores é executada seguindo o mesmo princípio. No código abaixo

pode-se observar seu funcionamento. Após habilitar a comunicação enviamos o endereço do

registrador com o MSB nulo. Com isso o chip entende que será feita uma leitura do valor do

registrador. Para executar a leitura dos registradores utilizamos a função SPI.transfer para

enviar um valor qualquer e coletamos o resultado da função. A cada valor enviado recebe-se

uma palavra de oito bits de informação. Ao coletar todos os bytes do registrador finaliza-se a

comunicação e retorna-se o valor contendo a informação completa.

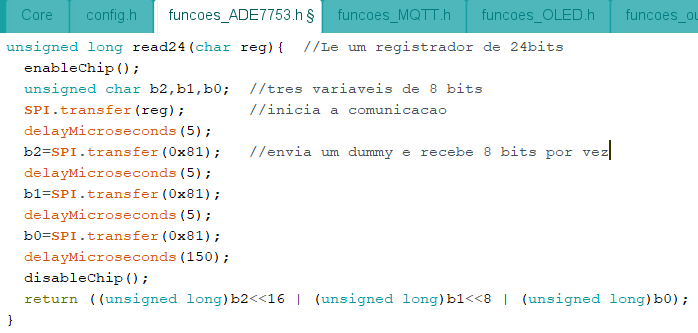
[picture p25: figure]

Figura 35 - Método de leitura dos registradores

A função valorMedio() permite a execução das funções de leitura dos registradores

várias vezes, soma seus valores e define um valor médio, para evitar imprecisões pontuais

nos valores mensurados. Ela recebe três parâmetros: a quantidade de amostras que devem

coletadas, a função de leitura que retorna os valores e o registrador a ser consultado.

Figura 36 - Método de cálculo de média

As funções de leitura dos parâmetros da rede são muito similares, os conceitos

aplicados a uma podem ser facilmente adaptados para o entendimento das demais. Citando

como exemplo a função de leitura da frequência da rede temos o código da Figura 37. A

função valorMedio() realiza 10 leituras do registrador PERIOD utilizando a função read16().

Este registrador possui o valor do período da onda que estamos monitorando no canal 2 do

ADE7753. Sabendo que desejamos obter a frequência que é dada pelo inverso do período, e

que o período depende do clock aplicado ao sistema, definimos uma equação para o cálculo

da frequência.

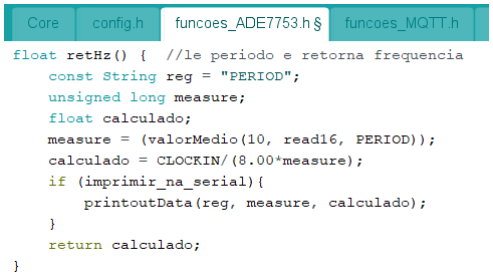
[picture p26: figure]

Figura 37 - Exemplo de método de retorno de valor

### 3.6.3 INTERFACE WEB

Os dados que são coletados pelo microcontrolador são enviados para o broker e ficam

armazenados em um serviço chamado Dynamo DB, que é um serviço de armazenamento de

dados da AWS. Para manipular estes dados temos várias opções dadas por um SDK. Estes

kits estão disponíveis para diversas linguagens conforme descrito na documentação do

desenvolvedor para Dynamo DB. Neste trabalho faremos uso da SDK para PHP.

Quando se deseja programar uma página web, tem-se como boa prática realizar a

escrita do código em uma estação local, para somente após a conclusão e os testes finais

exportar e disponibilizar o código completo para um servidor na internet. Para isso, utilizou-se

um computador com os mesmos serviços que serão posteriormente instalados na estação

EC2, que incluem o servidor Apache com interpretador PHP.

Após a instalação do servidor Apache, as páginas criadas estarão acessíveis através

do endereço de localhost do navegador. A programação deve ser feita dentro do diretório

‘htdocs’ do pacote XAMPP de hospedagem da página web que por padrão fica instalado na

raiz do sistema.

Criou-se uma pasta com o nome da nossa aplicação web dentro de ‘htdocs’ e então

teremos nosso espaço de trabalho preparado para iniciar a programação. Dentro desta pasta

faremos também o download dos arquivos SDK PHP para AWS [11] que nos permitirão a

consulta dos dados.

Conforme instruções da documentação, deve-se utilizar o seguinte trecho de código para incluir a SDK em nosso código. É necessário corrigir o endereço para o caminho correto

da biblioteca no nosso sistema.

Figura 38 - Inclusão da AWS SDK no projeto

Utilizamos o trecho de código a seguir para selecionar qual servidor estamos utilizando

e realizar a autenticação.

Figura 39 - Configuração de região e credenciais no código PHP

O código abaixo permite que se consulte dados na tabela chamada ‘IoTData’. São

passados três parâmetros: ‘device_id’, ‘begin_time’ e ‘end_time’, que selecionam o id do

dispositivo e intervalo de tempo no qual será feita a pesquisa. O resultado é devolvido em

formato de uma matriz pela variável $result. De posse dos resultados podemos manipulá-los

conforme desejado utilizando as diversas ferramentas PHP e HTML. O código final da

aplicação apresenta algumas alterações para permitir a seleção de um índice de registros,

permitindo a consulta de uma amostragem parcial dos valores conforme o período da busca.


Figura 40 – Solicitação de busca de dados em PHP

A aplicação web desenvolvida tem sua estrutura de arquivos definida conforme

apresentado na Figura 41.

Figura 41 - Estrutura de arquivos da aplicação web

## 4 RESULTADOS ALCANÇADOS

Infelizmente não foi possível obter resultados da comparação entre os valores medidos

pelo dispositivo e os valores reais aferidos por equipamentos calibrados conforme normas

internacionais, dado as dificuldades da pandemia covid-19. No entanto pode-se destacar o

conjunto de resultados alcançados o funcionamento de todos diversos componentes que

interagem neste sistema.

### 4.1 INTEGRAÇÃO

A configuração do módulo Node MCU foi concluída com sucesso e realizou a conexão

ao serviço de MQTT conforme se esperava. A integração do dispositivo com os serviços da

plataforma IOT Core foi executada com êxito. O envio dos dados foi realizado corretamente e

seu armazenamento também se comportou conforme o esperado.

### 4.2 INTERFACE WEB

A interface web apresentou incialmente alguns bugs que foram tratados, como, por

exemplo, erros durante a solicitação de dados que não existiam no banco de dados.

Também foi tratado um erro relacionado à busca de um número muito grande de dados em

uma única pesquisa, tornando a interface instável. Para resolução deste erro foi desenvolvido

um algoritmo que limita a quantidade de dados retornados, fazendo com que haja uma busca

seletiva do banco de dados dependendo do intervalo de pesquisa. Para intervalos muito

amplos, não é feita uma solicitação de todos os dados de maneira contínua, mas sim

amostrada por intervalos definidos pelo algoritmo de busca.

### 4.3 COMPUTAÇÃO NA NUVEM

O serviço de computação em nuvem EC2 utilizado para hospedagem da aplicação web

se mostrou muito confiável, não apresentou indisponibilidade e permitiu múltiplos acessos

sem apresentar lentidão ou travamentos. Após a realização da configuração inicial, o acesso

torna-se simples e não gera dificuldades para possíveis atualizações na programação dos

serviços hospedados.

### 4.4 MEDIÇÕES REALIZADAS

Os resultados relacionados à medição da rede elétrica realizada pelo circuito da Analog

Devices também apresentaram resultados coerentes. Conforme mencionado anteriormente, por motivo da pandemia covid-19 não houve acesso aos instrumentos de medição do IFSC,

logo, para a realização das simulações foram utilizadas cargas conhecidas que apesar de

não possuírem uma tolerância restrita de suas especificações de consumo, permitirão que

sejam realizados testes de funcionamento das medições. Parâmetros da rede que são muito

estáveis também são considerados como sendo parâmetros padrões para efeito de

comparação.

Utilizou-se um multímetro MINIPA TRUE RMS Modelo ET-1639 para realizar as

calibrações das medições de corrente e tensão e um multímetro Modelo FLUKE 107 para

comparações das medições de frequência da rede. Durante os testes utilizou-se de uma

carga estática puramente resistiva de 750 W.

A Figura 42 apresenta uma coleta de dados apresentada na interface web.

Figura 42 - Dados analisados

Os valores das medições realizadas não serão apresentados neste relatório devido à

imprecisão do sistema montado apenas em protoboard, no entanto, podemos validar o

funcionamento de todos os componentes analisando os resultados no escopo geral da Figura

42. Percebemos que os resultados, apesar de sofrerem influência de imprecisões das

calibrações sem equipamentos adequados e da instalação precária, são coerentes com a

realidade dos testes realizados.

No caso de uma montagem adequada com a confecção de placa de circuito impresso

as medições porem ter um resultado bem preciso, chegando a um máximo de 0,5% para

uma medição em fundo de escala, conforme a especificação da Analog Devices. Este erro

depende também da precisão dos outros componentes utilizados.

Desenvolveu se ainda uma seção de médias e estimativas de consumo que está

apresentada na Figura 43. Estes resultados são calculados apenas com os dados presentes

no gráfico e não como o conteúdo inteiro do banco de dados, logo, quanto maior o período

de amostragem mais preciso se mostra a estimativa. Essa estimativa é calculada e se baseia

na média diária, multiplicada pelo número de dias que tem um mês, que não leva em conta

outros fatores sazonais.

Estimativa

Figura 43 - Médias e estimativas de consumo

## 5 CONCLUSÕES

Como comentários conclusivos pertinentes a este trabalho, pode-se afirmar que os

objetivos propostos foram plenamente atingidos.

O hardware de aquisição, embora não fabricado, teve seu projeto em tamanho

compacto, sendo que o invólucro com todos os componentes apresentou as dimensões de

120 x 70 x 50 [mm].

O projeto do produto seguiu todas as premissas básicas de segurança para

equipamentos elétricos, como por exemplo, o isolamento galvânico do circuito de tensão da

rede do restante dos componentes. Além disso, manteve todos os componentes com risco

de choque elétrico protegidos pela barreira do invólucro de polímero, garantindo assim os

objetivos de oferecer segurança aos usuários. A instalação foi simplificada pela facilidade de

conexão em uma tomada elétrica e uso do sensor de corrente não invasivo no circuito.

O custo do produto ficou dentro das expectativas previstas, mas os custos dos serviços

da AWS devem ser considerados no caso de uma aplicação do produto em âmbito

comercial. Neste projeto foram utilizados os serviços oferecidos pela empresa gratuitamente

em uma conta para período de experimentação.

A plataforma web desenvolvida apresentou-se capaz de realizar as tarefas

especificadas de consulta e apresentação de dados para o usuário de maneira fácil de

utilizar e gerenciando os dados com clareza e agilidade.

O sistema concebido de medição dos diversos parâmetros de energia elétrica realizou

com êxito o envio dos dados e sua posterior hospedagem na nuvem por uma rede sem fio. O

acesso aos dados ficou protegido por um sistema seguro de login para consulta.

Um resultado que ficou aquém do esperado está relacionado à calibração das

medições e a ausência de testes elaborados envolvendo cargas indutivas e capacitivas.

Poderia ter sido desenvolvido um trabalho mais completo com ferramentas de calibração e

cargas adequadas que estavam disponíveis apenas nas instalações do instituto e ficaram

indisponíveis durante a escrita deste trabalho.

Apesar ausência da avaliação dos resultados de exatidão da medição, podemos

mencionar que o equipamento realiza de modo satisfatório o trabalho para o qual foi

desenvolvido conforme apresentado na seção 4.4.

As interfaces de usuário desenvolvidas trabalharam conforme o esperado, os serviços

de IOT também se mostraram confiáveis e o microcontrolador ESP8266 executou suas

funções com boa confiabilidade. Isso mostra que o sistema desenvolvido durante este

trabalho poderia servir como base para o desenvolvimento de um produto comercial sem a

necessidade de grandes mudanças.

Como melhorias futuras neste projeto, poderíamos citar a calibração correta do sistema

utilizando as ferramentas adequadas, melhorias no sistema de identificação do dispositivo,

para que os certificados e o id do dispositivo possam ser configurados externamente ao

código programado no microcontrolador. Uma sugestão poderia ser a de realizar a

configuração direta por meio de uma aplicação web hospedada no dispositivo que pode ter

um modo de configuração como ponto e acesso (AP) e outro modo como cliente, assim

como é realizado nos roteadores e outros dispositivos de internet. A confecção da placa de

circuito impressa e do invólucro de polímero para sua enclausura também são

melhoramentos que poderiam ser executados. Além disso, o chip AD7753 da Analog Devices

permite a leitura de algumas falhas na rede como, por exemplo, afundamentos de tensão,

picos de tensão entre outros que poderiam ser monitorados e gerar alertas nos próprios

dispositivos e registros específicos no banco de dados.

Também poderia ter sido feito um estudo sobre os custos financeiros de todos estes

serviços utilizados neste trabalho e comparar com serviços alternativos que podem ter um

melhor custo-benefício para o cliente. Os serviços da AWS tem um custo atrelado à

utilização, por isso foi utilizada uma taxa de uploads menor, causando uma perda de parte

das informações de consumo do ambiente monitorado. Talvez se possam obter custos

menores testando outros tipos de serviço que possam armazenar uma quantidade maior de

dados de maneira menos onerosa, além de executar os cálculos na própria plataforma para

restringir a quantidade de tráfego a ser transferida pela rede durante uma consulta.

### 5.1 DIFICULDADES ENCONTRADAS

Durante o projeto e o desenvolvimento deste trabalho, surgiram diversas dificuldades. A

maior dificuldade pode ter sido inexperiência com as tecnologias utilizadas. O autor não

possuía nenhum conhecimento relacionado à programação de páginas web ou com os

dispositivos utilizados. O circuito integrado ADE7753 utilizado também exige bastante

estudo, devido a sua complexidade. Os serviços da AWS possuem bastante documentação,

mas isso não significa que seu aprendizado seja trivial. Todos estes aspectos exigiram muita

dedicação do autor.

Uma dificuldade adicional que se apresentou durante a produção deste trabalho foi a

repercussão da pandemia COVID19, na qual o estado de quarentena foi mantido durante

todo o período de pesquisa e produção tanto da parte teórica quanto prática deste trabalho.

A suspensão das atividades escolares e o isolamento causaram uma redução dos recursos

disponíveis relacionados à estrutura física, disponibilidade de local de trabalho e

equipamentos da instituição. Todas as tarefas relacionadas a este trabalho foram executadas

no domicilio do autor, utilizando os equipamentos disponíveis. Isso pode ter prejudicado

parcialmente os resultados, porém manteve significativo o aprendizado com o

desenvolvimento deste trabalho.

## 6 REFERÊNCIAS

[1] - NICEGEAR. Datasheet: Current transformer. Modelo SCT013-020. Publicação

Eletrônica, 2020. Disponível em: https://nicegear.nz/obj/pdf/SCT-013-datasheet.pdf Acesso

em: 07 de abril de 2020.

[2] - GITHUB. Arduino core for the ESP32. 2018. Publicação eletrônica, 2020.

Disponível em https://github.com/espressif/arduino-esp32 Acesso em 09 de abril de 2020.

[3] | - | NODEMCU. | Features. | Publicação | Eletrônica, | 2020. | Disponível | em:

https://www.nodemcu.com/index_en.html Acesso em: 08 de abril de 2020.

[4] - FILIPEFLOP. Módulo WiFi ESP8266 NodeMcu ESP-12. Publicação Eletrônica,

2020. Disponível em: https://www.filipeflop.com/produto/modulo-wifi-esp8266-nodemcu-esp-

12/ (https://www.filipeflop.com/produto/modulo-wifi-esp8266-nodemcu-esp-12/) Acesso em 09 de abril de 2020.

[5] - ARDUINO. ESP8266 Arduino Core’s documentation. Publicação Eletrônica, 2020.

Disponível em: https://arduino-esp8266.readthedocs.io/en/latest/ Acesso em: 08 de abril de

2020.

[6] - ANALOG DEVICES. Datasheet: ADE7753. Publicação Eletrônica, 2010. Disponível

em: https://www.analog.com/media/en/technical-documentation/data-sheets/ADE7753.pdf

Acesso em: 08 de abril de 2020.

[7] - ESPRESSIF. Hardware ESP8266 Resources. Publicação Eletrônica, 2020.
Disponível | em: | https://www.espressif.com/en/products/hardware/esp8266ex/resources

Acesso em: 08 de abril de 2020.

[8] - ETT. A guide of Module OLED Model. OLED 1.3 I2C. Publicação Eletrônica, 2020.

Disponível em: http://www.ett.co.th/prod2017/OLED%201.3%20I2C%20ENG.pdf Acesso em:

08 de abril de 2020.

[9] - AWS. What Is Amazon DynamoDB? Publicação Eletrônica, 2020. Disponível em:

https://docs.aws.amazon.com/amazondynamodb/latest/developerguide/Introduction.html

Acesso em: 08 de abril de 2020.

[10] - AWS. PHP e DynamoDB. Publicação Eletrônica, 2020. Disponível em:

https://docs.aws.amazon.com/pt_br/amazondynamodb/latest/developerguide/GettingStarted.

PHP.html (https://docs.aws.amazon.com/pt_br/amazondynamodb/latest/developerguide/GettingStarted.PHP.html) Acesso em: 08 de abril de 2020.

[11] - AWS. Installing the AWS SDK for PHP Version 3. Publicação Eletrônica, 2020.
Disponível | em: | https://docs.aws.amazon.com/sdk-for-php/v3/developer-guide/getting-

started_installation.html (https://docs.aws.amazon.com/sdk-for-php/v3/developer-guide/getting-started_installation.html) Acesso em: 08 de abril de 2020.

[12] - AWS. Documentação do Amazon Elastic Compute Cloud. Publicação Eletrônica,

2020. Disponível em: https://docs.aws.amazon.com/ec2/index.html Acesso em: 08 de abril de

2020.

[13] - AWS. What Is AWS IoT? Publicação Eletrônica, 2020. Disponível em:

https://docs.aws.amazon.com/iot/latest/developerguide/what-is-aws-iot.html Acesso em: 08

de abril de 2020.

[14] - AWS. Connecting to Your Linux Instance from Windows Using PuTTY Publicação
eletrônica, | 2020. | Disponível | em:

https://docs.aws.amazon.com/AWSEC2/latest/UserGuide/putty.html Acesso em: 08 de abril

de 2020.

[15] - AWS. Como autorizar tráfego de entrada em suas instâncias. Publicação
Eletrônica, | 2020. | Disponível | em:

https://docs.aws.amazon.com/pt_br/AWSEC2/latest/UserGuide/authorizing-access-to-an-

instance.html (https://docs.aws.amazon.com/pt_br/AWSEC2/latest/UserGuide/authorizing-access-to-an-instance.html) Acesso em: 08 de abril de 2020.

[16] - 김동일. Connecting ESP8266 to AWS IoT Core using Arduino Mqtt. Publicação

Eletrônica, 2019. Disponível em: https://www.youtube.com/watch?v=4eF6bfIURN0 Acesso

em: 08 de abril de 2020.

[17] - GITHUB. Biblioteca PubSubClient.h . Publicação Eletrônica, 2019. Disponível em:

https://github.com/knolleary/pubsubclient/blob/master/src/PubSubClient.h Acesso em: 20 de

abril de 2020.

[18] - GOOGLE. Google Charts – Glossary. Publicação Eletrônica, 2020. Disponível em:

https://developers.google.com/chart/glossary Acesso em: 08 de abril de 2020.

[19] - APACHEFRIENDS. XAMPP Documentation. Publicação Eletrônica, 2020.

Disponível em: https://www.apachefriends.org/docs/ Acesso em: 08 de abril de 2020.

[20] - AMDS4. Comparação Shunts, Transformadores e Transdutores. Publicação
Eletrônica, | 2019. | Disponível | em: | https://blog.amds4.com.br/comparacao-shunts-

transformadores-e-transdutores/ (https://blog.amds4.com.br/comparacao-shunts-transformadores-e-transdutores/) Acesso em: 08 de abril de 2020.

[21] - YANASHI. TRANSDUTOR com Isolamento Galvânico. Publicação Eletrônica,
2020. | Disponível | em: | http://yanashi.com.br/data/documents/Catalogo-Transdutor-com-

Isolamento-Galvanico.pdf (http://yanashi.com.br/data/documents/Catalogo-Transdutor-com-Isolamento-Galvanico.pdf) Acesso em: 08 de abril de 2020.

[22] - IEFP. Medições de Ondas Sinusoidais. Publicação Eletrônica, 2020. Disponível

em: https://elearning.iefp.pt/pluginfile.php/49293/mod_resource/content/0/Electricidade_-

_Electronica/Electricidade/Onda%20Sinusoidal/Medicoes%20de%20uma%20Onda%20Sinus

oidal.pdf (https://elearning.iefp.pt/pluginfile.php/49293/mod_resource/content/0/Electricidade_-_Electronica/Electricidade/Onda%20Sinusoidal/Medicoes%20de%20uma%20Onda%2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) Acesso em: 08 de abril de 2020.

[23] - AYUSH GEMINI. MQTT in Android. Publicação Eletrônica, 2019. Disponível em:

https://medium.com/@ayushgemini/mqtt-in-android-ed87b5278193 Acesso em:09 de abril de

2020.

## APÊNDICE A – CÓDIGO FONTE

Todos os códigos de programação encontram-se disponíveis no seguinte endereço:

https://github.com/cristianritter/EnergyMeter

## APÊNDICE B – CONFIGURAÇÃO DOS SERVIÇOS AWS

Inicialmente é necessária a criação de uma conta na AWS por meio do link

aws.amazon.com/pt.

Preenchemos os dados solicitados

As contas da AWS incluem 12 meses de acesso ao nível gratuito que começa a contar

a partir da inscrição contemplando mensalmente o uso de até 5Gb para armazenamento no

banco de dados Dynamo DB e 250 mil mensagens publicadas ou recebidas pelo serviço IoT

Core.

Após a conclusão de todos os passos de criação e verificação da conta podemos

acessar o console de gerenciamento AWS.

A | partir | do | console | de | gerenciamento | acessamos | a | guia | Serviços.

Na caixa de busca temos acesso aos serviços que iremos utilizar.

Conta - Billing

Primeiramente iremos habilitar a conta adicionando uma forma de pagamento, para isso

podemos fazer uma busca por Billing, acessar o serviço e a guia Métodos de Pagamento.

Após a configuração de um método de pagamento e ativação do faturamento a conta está

pronta para utilização. Mesmo a utilização gratuita exige o cadastro de uma forma de pagamento para verificação. É possível que hajam cobranças caso o uso do serviço exceda

as cotas definidas para uso gratuito.

Permissões - Policy

A próxima etapa necessária envolve a criação de uma política de acesso utilizando o

serviço de identificação IAM que também pode ser encontrado utilizando a caixa de busca.

Iremos realizar primeiramente a criação de uma nova Política, para isso acessamos a

guia Políticas e então clicamos no botão Criar Política.

Faremos a seleção do tipo de serviço utilizando a opção Escolha um serviço.

Buscamos pelo serviço IoT.

Após a seleção do serviço IoT, configuramos as ações permitidas marcando a caixa

chamada Todas as ações IoT (iot:*).

Na guia recursos selecionamos a opção Todos os recursos.

Avançamos para a revisão selecionando Revisar Política

Adicionamos um nome e uma descrição à política e então selecionamos Criar política

Dispositivos - Things

Após a criação da política de acesso, acessamos novamente a caixa de busca e

buscamos por IoT Core para a criação de uma “thing” que será fará as publicações.

Dentro da página do serviço IoT Core, acessamos a guia Gerenciar.

Criamos um dispositivo utilizando o botão Criar.

Realizamos a criação de um dispositivo único utilizando o botão Criar uma única coisa.

Preenchemos o campo com um nome definido para o dispositivo

Podemos deixar os outros campos do modo que estão e avançamos para a próxima

etapa.

Nesta etapa vamos adicionar um certificado por meio da opção “Criar certificado”.

Após a criação do certificado, precisamos realizar o download do certificado, da chave

pública, da chave privada e da CA raiz para o AWS IoT. Salvamos todos estes arquivos em

uma pasta conhecida para uso posterior.

O download da CA raiz para o AWS IoT é feita de um modo um pouco diferente das

demais. Ao clicar em Download somos direcionados pra outra página na qual devemos abrir

o link chamado Amazon Root CA 1.

Este link abrirá um arquivo de certificado. Podemos salva-lo clicando com o botão

direito do mouse e selecionando Save as...

Antes de salvar alteramos o tipo de arquivo para All files e salvamos com o nome

original | juntamente | à | pasta | com | as | outras | três | chaves | e | certificados.

Após o download dos arquivos voltamos a página anterior e clicamos em Ativar.

Em seguida clicamos em Anexar uma política

Selecionamos a política criada anteriormente e clicamos em Registrar a coisa

Neste ponto nosso broker IOT está preparado para receber dados do nosso dispositivo.

DynamoDB - Configurando Ações

Podemos configurar uma ação a ser executada pelo serviço IoT Core ao receber uma

mensagem em determinado tópico. Para isso acessamos o serviço

E acessamos a guia Agir

Criamos uma nova regra clicando em

Completamos os dados solicitados

Configuramos as instruções de consulta das regras

Neste caso estamos selecionando todos os dados do tópico iot/topic.

Adicionamos uma ação e selecionamos o envio dos dados para uma tabela do

DynamoDB como colunas separadas.

Ao final da página selecionamos

E então criamos um novo recurso (tabela no Dynamodb para acomodar nossos dados)

Seremos direcionados para a plataforma do serviço Dynamo DB. Clicamos em Criar

tabela

Especificamos os detalhes da tabela que incluem nome, chave primaria e chave de

classificação.

A chave de partição em conjunto com a chave de classificação, não podem se repetir.

Logo temos que garantir que não existam dois registros idênticos sob o risco de serem

substituídos.

Clicamos em Criar

Estaremos com a tabela criada e podemos voltar ao console e selecionar AWS IoT

Core.

Repetimos os passos anteriores e selecionamos a tabela criada.

Selecionamos a regra que nos da autorização para executar as ações, essa regra é

criada em IAM. Se não houver uma regra podemos criar.

Clicamos em Adicionar ação

E então clicamos em

Se quiséssemos, poderíamos também criar uma regra para publicação em caso de

erros, como, por exemplo uma que publicasse em um tópico aws/rules/erros.

Assim poderíamos assinar o tópico e verificar se algum erro está sendo gerado.

Temos tudo criado conforme exibido abaixo.

Agora vamos testar a regra.

Para isso vamos abrir nossa tabela no DynamoDB

Acessamos o console AWS e então DynamoDB, após isso procuramos a guia Tabelas

E Selecionamos a nossa tabela e a guia Itens

Podemos ver que não existem itens ainda.


Agora vamos publicar no tópico iot/topic utilizando a ferramenta de testes do modulo

AWS IoT

Para isso acessamos o console AWS e procuramos por AWS Iot Core

E então acessamos a guia Teste

Antes de publicar podemos assinar o tópico para verificar a mensagem que será

enviada.

Agora vamos publicar, para isso clicamos em publicar em um tópico

Definimos o tópico no qual publicar e a mensagem a ser publicada. Na mensagem

enviaremos um Array JSON contendo os dados definidos na tabela como chave primaria e

de classificação assim como outros dados quaisquer. Precisamos manter o padrão de chave

e valor, sendo que a chave é a primeira coluna e o valor será adicionado às linhas de dados.

O valor de chaves primaria e secundária precisam estar presentes e corretos para que não

ocorram erros.

Enviamos clicando em Publicar.

Podemos perceber que foi recebida uma mensagem no tópico

Agora vamos verificar se os valores foram corretamente adicionados à database do

Dynamodb.

Na página onde estão os itens acionamos o botão de atualizar itens

Podemos ver que os itens foram adicionados corretamente.

Se ocorrer algum erro, verifique as permissões em IAM, buscando pelas políticas das

funções de Iot. Tais políticas foram criadas juntamente à criação da ‘thing’.

Instância E2C - Criação

Partindo do console de gerenciamento da AWS, localize o serviço EC2.

Acesse a guia Instances.

E acesse o botão Launch Instance.

Selecione o sistema operacional e clique em Select.

Selecione o tipo de instancia e clique em Review and Launch.

Será solicitada que seja criada uma chave de acesso. Crie uma chave ou utilize a

mesma utilizada anteriormente. Ela será necessária para acessar a sessão da maquina

posteriormente.

Aguarde até que a instancia seja preparada e apresente o status conforme a imagem.

Instância E2C - Acesso remoto

O acesso a instancia é realizado remotamente utilizando o protocolo SSH seguindo as

instruções a seguir.

Clique em Conect

Uma janela com as informações de conexão será exibida.

Faça o download e utilize o aplicativo PuTTygen para converter a chave anteriormente

gerada com extensão .pem em .ppk. Importe a chave .pem e clique em Save private key.

Na guia session adicione o seu endereço de dns personalizado conforme apresentado

nas instruções de sua sessão.

Após acesse a guia de Configurações SSH e selecione o certificado criado

anteriormente.

Clique em Open.

Agora estamos conectados a sessão remota de nossa estação Linux de Cloud

Computing AWS. Podemos dar continuidade instalando os serviços que utilizaremos.

Instância E2C - Instalação de serviços

Instalação do Xampp na estação remota.

Verifique | o | link | com | a | versão | atualizada | do | endereço

https://sourceforge.net/projects/xampp/files/XAMPP%20Linux/

https://sourceforge.net/projects/xampp/files/XAMPP%20Linux/7.4.3/xampp-linux-x64-

7.4.3-0-installer.run/download (https://sourceforge.net/projects/xampp/files/XAMPP%20Linux/7.4.3/xampp-linux-x64-7.4.3-0-installer.run/download)

Faça o download da última versão do XAMPP para o seu sistema e salve-o com o

nome xampp-installer.run com o seguinte comando:

wget “https://sourceforge.net/projects/xampp/files/XAMPP%20Linux/7.4.3/xampp-linux-

x64-7.4.3-0-installer.run/download” -O xampp-installer.run

Torne o arquivo executável com o comando:

chmod +x xampp-installer.run

Inicie a instalação do XAMPP, com o comando;

sudo ./xampp-installer.run

Quando aparecer, siga os passos do assistente de instalação e configuração:

Responda Y para todos os questionamentos.

Para iniciar o Apache, use:

sudo /opt/lampp/xampp startapache

Precisamos ainda liberar o acesso para serviços HTTP na maquina criada. Para isso

voltamos em instancias e selecionamos Security Groups.

Editamos as regras de entrada

Adicionamos uma regra para acesso HTTP para todos os endereços IP.

Agora podemos acessar nosso servidor apache usando o DNS publico da estação.

Estamos com a página padrão do XAMPP.

Instância E2C - Servidor web

Vamos utilizar o WINSCP para transferir nossa própria pagina da web para o servidor.

Antes de continuar precisamos colocar uma senha de root em nosso servidor.

Para isso use os comandos su para acessar a super user da instância remota use o

comando passwd para definir uma nova palavra passe.

Execute a instalação do WINSCP no computador local e importe as configurações do

Putty

Agora temos acesso ao sistema de arquivos do nosso servidor.

Os arquivos do servidor apache ficam localizados na pasta /opt/lampp/htdocs. Vamos

substituí-los pelos arquivos de nossa aplicação web.

Mas não podemos editar diretamente pelo WINSCP, pois nosso acesso remoto não

permite.

Vamos copiar nossos arquivos de projeto para uma pasta temporária no

home/ubuntu/htdocs/

E após a conclusão iremos utilizar o Putty para mover essa pasta para

/opt/lampp/htdocs utilizando o superusuario.

Primeiramente iremos renomear a pasta atual do XAMPPs para BKP utilizando os

comandos:

cd /opt/lampp/htdocs

mv htdocs/ bkp/

Movemos o novo conteúdo para a pasta com o comando:

mv /home/ubuntu/htdocs/ htdocs/

Agora nosso servidor está funcionando corretamente e disponível através da internet.

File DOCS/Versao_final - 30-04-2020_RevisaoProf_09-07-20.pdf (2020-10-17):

INSTITUTO FEDERAL DE EDUCAÇÃO, CIÊNCIA E TECNOLOGIA DE

SANTA CATARINA

CAMPUS FLORIANÓPOLIS

DEPARTAMENTO ACADÊMICO DE METAL-MECÂNICA

CRISTIAN FERNANDO RITTER

## MEDIDOR DE ENERGIA MONOFÁSICO DE BAIXA

## TENSÃO BASEADO EM REDES SEM FIO

TRABALHO DE CONCLUSÃO DE CURSO

FLORIANÓPOLIS - SC

2020

CRISTIAN FERNANDO RITTER

## MEDIDOR DE ENERGIA MONOFÁSICO DE BAIXA

## TENSÃO BASEADO EM REDES SEM FIO

FLORIANÓPOLIS - SC

2020

Trabalho de Conclusão de Curso de Graduação,

apresentado à disciplina de Trabalho de Conclusão

de Curso, do curso de Engenharia Mecatrônica, do

Departamento Acadêmico de Metal-Mecânica, do

Instituto | Federal | de | Educação, | Ciência | e

Tecnologia de Santa Catarina, como requisito

parcial à obtenção do título de Engenheiro

Mecatrônico.

Orientador Prof. Valdir Noll, Dr. Eng.

## RESUMO

RITTER, Cristian Fernando. MEDIDOR DE ENERGIA MONOFÁSICO DE BAIXA

TENSÃO BASEADO EM REDES SEM FIO. 85 f. Trabalho de Conclusão de Curso

(Graduação) – Curso de Engenharia Mecatrônica, Instituto Federal de Educação, Ciência e

Tecnologia de Santa Catarina. Florianópolis, 2020.

Neste trabalho propõe-se o desenvolvimento de um sistema para medição de energia

monofásico de baixa tensão baseado em redes de comunicação de dados sem fio que

realizará o monitoramento de diversos parâmetros elétricos da rede e seu registro em um

serviço de banco de dados. O sistema será desenvolvido em um microcontrolador que

enviará os dados para um serviço de Internet das Coisas. Uma interface web permitirá a

filtragem e consulta dos dados de qualquer lugar por meio de um acesso à internet. O banco

de informações adquirido poderá ser usado para inúmeros fins, que incluem: traçar um

padrão de consumo do local, definir estatisticamente a estimativa do consumo, verificar

informações relacionadas à conformidade do fornecimento de energia elétrica e possíveis

problemas na instalação elétrica, como desperdício de energia ou problemas no coeficiente

de fator de potência. Além disso, este sistema pode colaborar na realização de mudanças

nos hábitos de consumo que permitam aprimorar a eficiência energética do ambiente

monitorado.

Palavras chave: Internet das Coisas, monitor de energia, microcontroladores, sensores

de corrente e tensão.

## ABSTRACT

RITTER, Cristian Fernando. LOW-VOLTAGE SINGLE-PHASE POWER METER BASED

ON WIRELESS NETWORKS. 85 f. Trabalho de Conclusão de Curso (Graduação) – Curso de

Engenharia Mecatrônica, Instituto Federal de Educação, Ciência e Tecnologia de Santa

Catarina. Florianópolis, 2020.

This work proposes the development of a measuring single-phase low voltage energy

system based on a wireless network that will monitor several electrical grid parameters and

record them in a database service. This system will be developed in a microcontroller that will

use Internet of Things data. Web interface will allow filtering and querying data from anywhere

that has internet access. Collected database can be used for a number of purposes, which

include: drawing a consumption pattern, prediction, information related to the conformity of

the electricity and to investigate electrical installation troubles, such as waste of electricity and

problems with the power factor coefficient. In addition, this system can collaborate to make

changes in consumption habits allowing energy efficiency improvements.

Keywords: Internet of Things, energy monitor, microcontrollers, current and voltage

sensors.

## LISTA DE FIGURAS

Figura 18 – Diagrama de utilização de transformadores de corrente. Fonte: Analog Devices

Todas as figuras que não possuem fontes informadas são de autoria própria.

## LISTA DE EQUAÇÕES

## LISTA DE SIGLAS

ADC | Analogic to digital converter (conversor analógico-digital)
ABESCO | Associação Brasileira das Empresas de Serviços de Conservação de Energia
AC | Alternate Current (corrente alternada)
AGND | Analogic Ground (ground do circuito analógico)
AP | Access Point (ponto de acesso à rede sem fio)
AVDD | Tensão de alimentação positiva do circuito analógico
AWS | Amazon Web Services
CSS | Cascading Style Sheets
CT | Current Transformer (transformador de corrente)
DC | Direct Current (corrente continua)
DGND | Digital Ground (ground do circuito digital)
DVDD | Tensão de alimentação positiva do circuito digital
EC2 | Elastic Compute Cloud
GND | Ground
GPIO | General Purpose Input/Output
HTML | Hyper Text Markup Language
I2C | Inter-Integrated Circuit
IDE | Integrated Development Environment
IOT | Internet of things (internet das coisas)
JSON | Java Script Object Notation
LSB | Least Significant Bit (bit menos significativo)
MQTT | MQ Telemetry Transport
MSB | Most Significant Bit (bit mais significativo)
PHP | Hypertext Preprocessor
PWM | Pulse-Width Modulation
RMS | Root mean square

SLA | Service Level Agreement (termos do acordo de serviço)
SPI | Serial Peripheral Interface
TCP/IP | Internet protocol suite
UTC | Coordinated Universal Time
UTS | Unix Time Stamp

## SUMÁRIO

## 1 INTRODUÇÃO

Concorrentemente à popularização da internet e sua disponibilização sobre diversas

formas de propagação, muitas delas sem a necessidade de fios, houve também a ampliação

da gama de dispositivos com dimensões reduzidas e baixo consumo que podem acessar tais

redes e compartilhar dados de sensoriamento e até mesmo de controle para sistemas nas

mais diversas áreas, com uma ótima relação de custo benefício. Isso tem incentivado uma

cada vez mais evidente tendência de interconexão e monitoração de dispositivos e

ambientes, não somente industriais, mas também domésticos.

Diante da necessidade de coleta e análise de grandes quantidades de dados, surgiram

diversas empresas que oferecem serviços de tratamento e armazenamento de dados em

servidores remotos. Tais serviços dispensam a necessidade de quaisquer servidores ou

infraestrutura hospedada localmente para manter um serviço disponível online.

Dispondo do recente amadurecimento das tecnologias citadas acima, propõe-se neste

trabalho o desenvolvimento de um sistema para medição de energia monofásica de baixa

tensão baseado em rede sem fio que realizará o monitoramento e registro de diversos

parâmetros elétricos da rede. A medição dos parâmetros elétricos da rede será feita

utilizando um circuito integrado especificamente desenvolvido para este fim. Utilizar-se-á um

microcontrolador com interface de rede sem fio integrada para leitura, processamento e envio

de informações que serão armazenados em um serviço de armazenamento de dados online.

As análises e os resultados obtidos poderão ser consultados diretamente pela internet em

uma aplicação web desenvolvida para este fim.

Os dados obtidos poderão ser utilizados para diversos fins, como por exemplo, definir

estatisticamente a previsibilidade do consumo, verificar informações relacionadas à

conformidade do fornecimento de energia elétrica e possíveis mudanças nos hábitos de

consumo que permitam aprimorar a eficiência energética do ambiente monitorado.

### 1.1 OBJETIVOS

### 1.1.1 OBJETIVO GERAL

Desenvolvimento de um sistema que permita monitorar a qualidade de fornecimento e o

consumo de energia elétrica de uma residência ou outro ambiente. O sistema permitirá a

visualização dos dados em uma interface com gráficos de consumo em retrospecção, além

de análises baseadas nos hábitos de consumo registrados.

Os principais requisitos de projeto são:

- O hardware de aquisição dos dados deve ser compacto.
- O produto deve oferecer segurança ao usuário e fácil instalação.
- O custo do produto final deve ser um dos itens a ser considerado na escolha

dos componentes eletrônicos.

- O acesso do usuário à interface de consulta dos dados e resultados deve ser

feita de maneira simples e prática por meio de uma interface de aplicativo ou página

da web na internet.

- O dispositivo de medição deve ser capaz de enviar os dados para o banco de

dados por meio de redes sem fio.

- O acesso aos dados deve estar protegido de acessos indevidos por meio de

autenticação de usuário e senha ou outra tecnologia similar.

### 1.1.2 OBJETIVOS ESPECIFICOS

Para facilitar a organização deste trabalho e tentar garantir que todos os requisitos

citados no objetivo principal sejam atingidos com sucesso, foram elaborados objetivos

específicos que servirão como metas sequenciais a serem alcançadas durante o

desenvolvimento. Como itens de uma lista inicial de objetivos específicos podem ser

alistados:

- Descrição em esboço de funcionamento do sistema.
- Análise dos fluxos de dados e de viabilidade técnica e econômica.
- Pesquisa e definição das tecnologias e componentes a serem utilizadas.
- Estudo e descrição de todas as tecnologias e componentes envolvidos no

projeto.

- Elaboração dos diagramas elétricos e eletrônicos.

- Programação dos dispositivos eletrônicos e das plataformas de back-end.
- Execução de testes e correções.
- Programação das plataformas de front-end.
- Montagem de protótipo.
- Testes, correções e aprimoramentos finais.
- Apresentação dos resultados.

### 1.2 JUSTIFICATIVA

A utilização racional de energia é um ponto de pauta importante à medida que o mundo

procura pensar e agir de modo sustentável. Conforme relatório divulgado pela Associação

Brasileira das Empresas de Serviços de Conservação de Energia (ABESCO) e noticiado pelo

jornal O Estadão, o desperdício de energia custou mais de R$60 bilhões para a economia

brasileira nos anos de 2015 a 2017. Além do prejuízo econômico, o uso indiscriminado da

energia aumenta a geração de gases nocivos para a atmosfera, sendo responsável por uma

parcela no efeito.

No Brasil, a maior parte da geração de energia elétrica provém de usinas hidrelétricas,

ficando, portanto suscetíveis a mudanças climáticas e a períodos de estiagens, bem como

afeta o ambiente quando se necessita ampliar a produção, pois exigem grandes áreas

territoriais. Diante da ocorrência de longos períodos sem chuvas, outras formas de geração

de energia podem ser utilizadas, porém muitas delas geram maior poluição e possuem maior

custo por kwh gerado.

Para tentar analisar e corrigir os hábitos de consumo de energia, precisa-se mensurar

adequadamente o consumo de energia de modo adequado. Neste aspecto, o medidor de

energia elétrica da concessionária de energia não se mostra eficiente, pois não permite a

visualização remota nem a criação de um banco de dados retrospectivo de consumo, além

de não diferenciar os dados de cada ambiente.

A proposta deste trabalho é desenvolver um sistema capaz de facilitar a medição da

energia elétrica em residências ou ambientes similares, permitindo que sejam coletados

dados zoneados do consumo. Este sistema será capaz de informar quanto cada

equipamento está consumindo, e em quais horários.

Com um mapa de consumo completo do ambiente podem ser tomadas medidas

assertivas com o objetivo de substituir equipamentos de baixa eficiência energética e

identificar gargalos de consumo. Ampliando-se a utilização de um sistema como esse a nível

nacional, certamente poderiam ser minimizados o desperdício de energia e a necessidade de

constantes investimentos em infraestrutura de geração e distribuição de energia, além de

colaborar para um melhor uso dos recursos naturais.

### 1.3 METODOLOGIA

Conforme descrito nos objetivos, este projeto é um dispositivo de ‘Internet das Coisas’ e

utiliza plataformas de serviços disponibilizados online para evitar a necessidade de hospedar

servidores localmente. O sistema é formado por diversos serviços trabalhando em conjunto,

sendo cada um responsável por tarefas especificas.

Seu desenvolvimento tem caráter experimental, contemplando o projeto de um protótipo

de dispositivo para medição e a programação dos firmwares e códigos fontes das aplicações

necessárias. Além disso, será necessária a configuração de diversos serviços para a

integração dos componentes em nuvem computacional. O estudo necessário para o

desenvolvimento de tais atividades será realizado com base na documentação

disponibilizada pelos serviços web, documentações de bibliotecas, bem como também, na

informação presente nos manuais de componentes e em experiências de autores que

desenvolveram trabalhos semelhantes anteriormente.

Com a finalidade de facilitar o entendimento ao expor a integração esperada entre os

sistemas que serão desenvolvidos, será apresentado um esboço geral do sistema proposto.

### 1.3.1 ESBOÇO GERAL DO SISTEMA

A Figura 1 ilustra o relacionamento entre o conjunto dos serviços de computação em

nuvem, dos dispositivos de aquisição de dados e da interface com o usuário.


Figura 1 - Esboço geral do sistema.

Será produzido um protótipo de dispositivo eletrônico medidor de energia chamado de

Energy Meter, que executará o envio das informações adquiridas para um broker que

interpretará os dados e armazenará em um banco de dados online. Estes dados podem ser

consultados por meio de requisições realizadas de uma página web especificamente

desenvolvida para este fim que será disponibilizada por um serviço de hospedagem.

### 1.4 ESTRUTURA DO DOCUMENTO

A documentação deste projeto está dividida em capítulos para facilitar a organização,

sendo: Introdução, Fundamentação teórica, Desenvolvimento, Resultados e Conclusão.

Na Introdução estão contidas diversas informações iniciais, que incluem considerações

sobre o tema e o trabalho proposto. Nesta seção são definidos também os requisitos de

projeto, os objetivos e as razões que justificam o seu desenvolvimento.

A fundamentação teórica apresenta o estudo do conhecimento de base necessário para

a execução deste trabalho, com informações sobre todos os componentes, tecnologias,

linguagens de programação e formatos de dados utilizados. Todas as funcionalidades relevantes das plataformas serão explicadas, assim como seu funcionamento no presente

projeto. O embasamento do estudo das grandezas físicas mensuradas também estará

descrito nesta seção.

No Desenvolvimento estão descritas as razões que influenciaram a escolha dos

serviços e componentes escolhidos, e apresentados o circuito eletrônico e seu

funcionamento. São descritos os principais trechos de programação e as principais funções.

Na seção de Resultados apresenta-se um resumo e análises dos dados coletados

durantes os testes do protótipo produzido. Finalizando este capítulo são apresentadas as

principais dificuldades encontradas durante o desenvolvimento do trabalho.

A Conclusão apresenta observações relacionadas às expectativas com este projeto,

comentários oportunos sobre os objetivos que foram alcançados e sugestões de

aprimoramentos e desenvolvimentos para outros trabalhos.

## 2 FUNDAMENTAÇÃO TEÓRICA

### 2.1 SENSORES DE CORRENTE E TENSÃO

Serão utilizados sensores de tensão e corrente para a leitura dos parâmetros da rede.

O circuito integrado ADE7753 nos permite a utilização de diversos tipos de sensores.

Precisamos entender então a diferença entre eles para a seleção do sensor e sua correta

utilização.

### 2.1.1 SHUNTS RESISTIVOS

É composto basicamente por um resistor de baixo valor em série com a carga,

dimensionado de maneira que a queda de tensão seja bem pequena. Partindo-se do

princípio de que a queda de tensão é proporcional a corrente, pode-se mensurar a corrente

utilizando este tipo de sensor.


Figura 2 - Shunts resistivos. Fonte: AMDS4 (2020)

### 2.1.2 TRANSDUTORES DE EFEITO HALL

São dispositivos capazes de medir o fluxo de corrente com total isolamento galvânico,

isto é, sem a necessidade de inserir o dispositivo em série no circuito a ser medido. Podem

trabalhar com vários tipos de forma de onda e em uma ampla faixa de frequência. Possuem

uma saída em corrente determinada através de uma relação entrada / saída e possuem um

resistor de saída para transformar a saída de corrente em um valor de tensão. Pode-se

trabalhar com correntes alternadas ou contínuas, mas necessita de fonte de alimentação

auxiliar para o circuito hall.


Figura 3 - Transdutores de Efeito Hall. Fonte: AMDS4 (2020)

### 2.1.3 TRANSFORMADOR DE CORRENTE

Um transformador de corrente [1] (conhecido como CT (Current Transformer)) é um

dispositivo que reproduz no seu circuito secundário, a corrente que circula em um

enrolamento primário com sua posição vetorial substancialmente mantida, em uma proporção definida, conhecida e adequada. É de baixo custo e serve apenas para correntes

alternadas.


Figura 4 - Transformadores de Corrente. Fonte: AMDS4 (2020)

### 2.1.4 BOBINA DE ROGOWSKI

Na sua forma mais simples, a bobina de Rogowski é um sensor de corrente composto

por uma bobina enrolada uniformemente com muitas (N) voltas por metro em um núcleo não

magnético de área transversal constante. Por não possuir núcleo magnético, possui baixa

inércia eletromagnética, permitindo assim a medição de altas frequências com bastante

precisão. Serve apenas para correntes alternadas (AC).


Figura 5 - Bobinas de Rogowski. Fonte: AMDS4 (2020)

### 2.1.5 ISOLAMENTO GALVÂNICO

Segundo a fornecedora YANASHI o isolamento galvânico em transdutores se faz

necessário quando se deseja que duas grandezas elétricas associadas fiquem separadas

eletricamente com o objetivo de atenuar interferências que possam causar danos ou

distúrbios aos circuitos ligados na saída do transdutor isolador. O isolamento colabora com a

segurança do circuito em casos de tensões altas, permitindo que a leitura do valor de

sensoriamento possa ser feita em uma tensão menor respeitando uma razão conhecida.
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

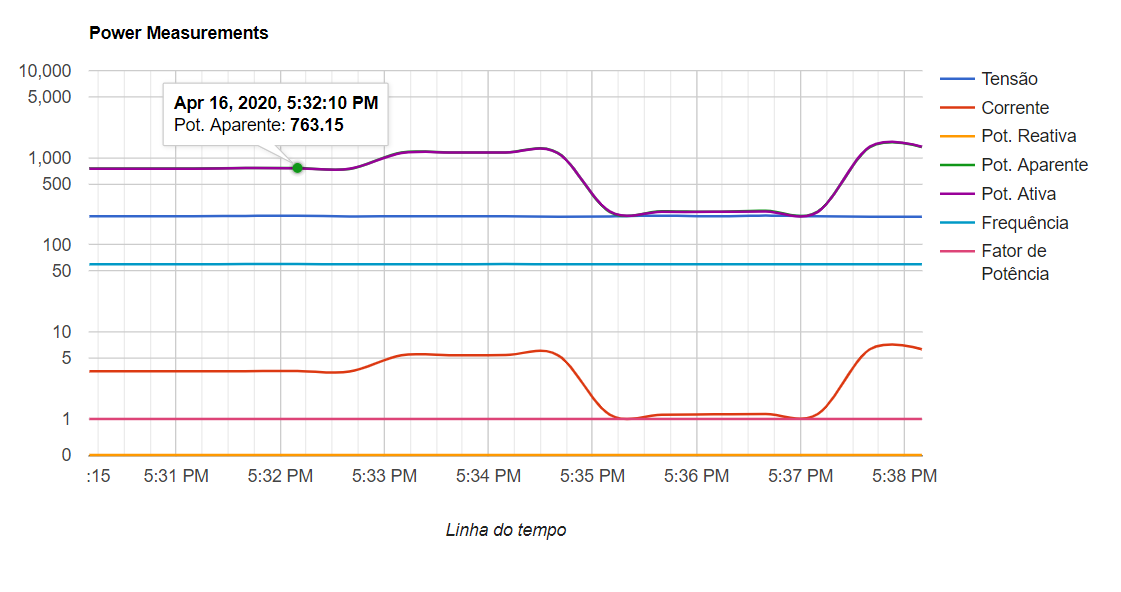
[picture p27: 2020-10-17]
DOCS/Ilustracoes/analise dados.png

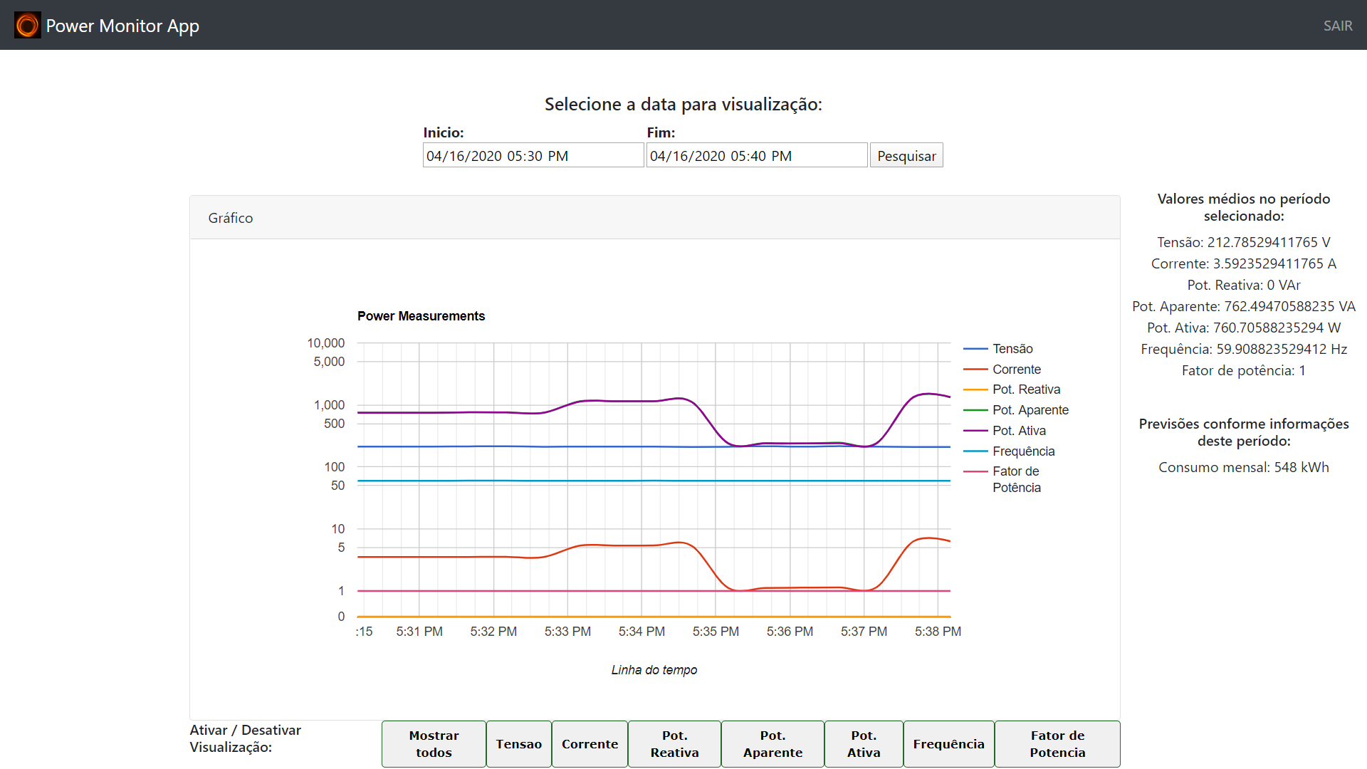
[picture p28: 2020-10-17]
DOCS/Ilustracoes/tela app web.png

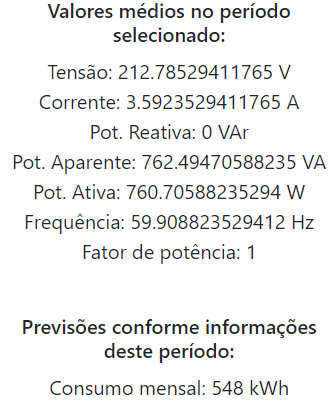
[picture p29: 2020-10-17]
DOCS/Ilustracoes/medias.png

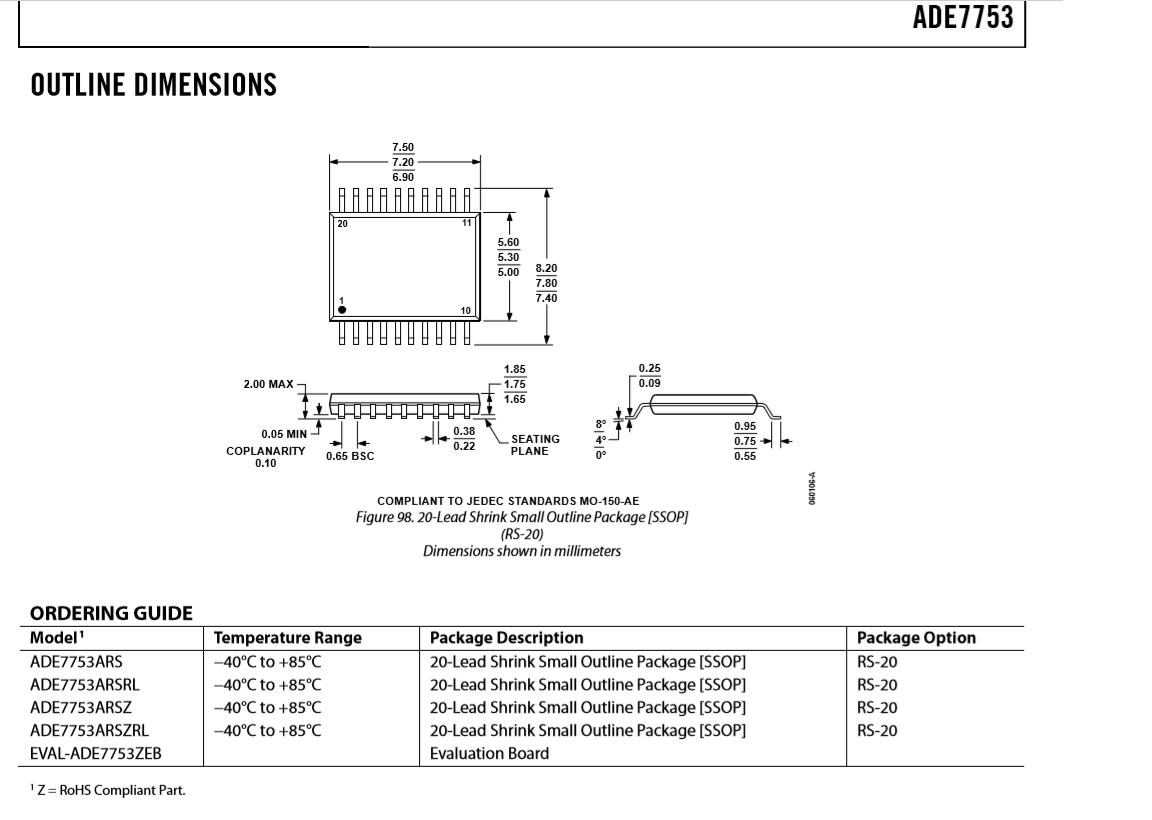
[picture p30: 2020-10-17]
Projeto/projeto-pci/Proteus_library/ade7753 dimensions.png

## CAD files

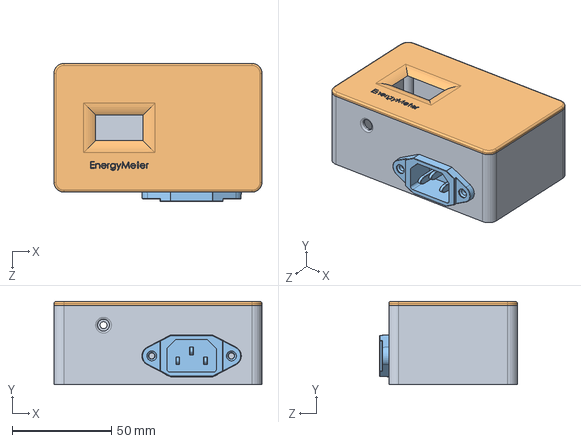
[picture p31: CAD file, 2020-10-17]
Projeto/montagem_caixa.SLDASM
105.0 x 42.0 x 69.8 mm
Conector IEC C14 Entrada

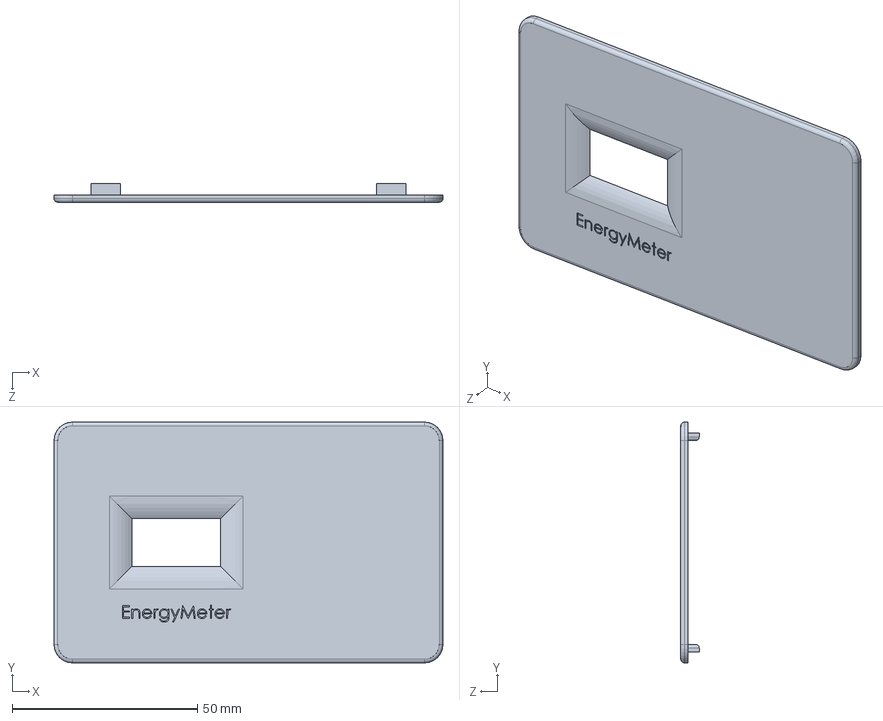
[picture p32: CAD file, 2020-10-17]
Projeto/cover.sldprt
105.0 x 65.0 x 5.00 mm

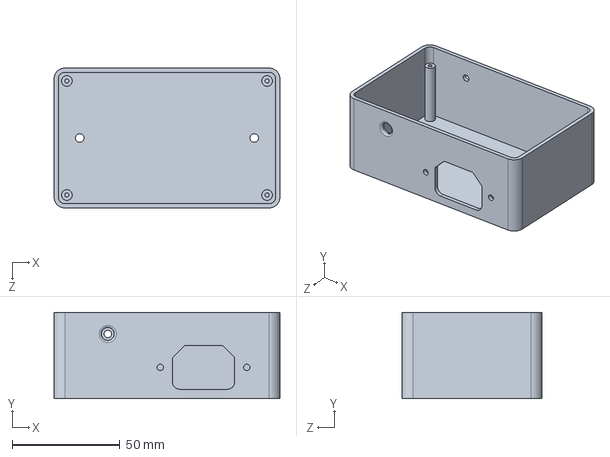
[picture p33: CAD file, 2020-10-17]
Projeto/box.SLDPRT
105.0 x 40.0 x 65.0 mm

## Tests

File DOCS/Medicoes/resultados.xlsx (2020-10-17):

 | Tensao | Corrente | Pot. Reativa | Pot. Aparente | Pot. Ativa | Frequencia | Fator de potencia
Medição 1 | 212.66 | 3.54 | 0 | 752.02 | 752.02 | 59.89 | 1
Medição 2 | 212.89 | 3.53 | 0 | 753.79 | 753.8 | 59.87 | 1
Medição 3 | 212.57 | 3.53 | 0 | 752.04 | 752.05 | 59.88 | 1
Medição 4 | 214.67 | 3.54 | 0 | 760.56 | 760.57 | 60.01 | 1
Medição 5 | 215.61 | 3.55 | 0 | 763.15 | 763.16 | 60 | 1
Medição 6 | 211.8 | 3.5 | 0 | 743.32 | 743.33 | 59.86 | 1
Desvio padrão: | 1.45237 | 0.01722 | 0.00000 | 7.04976 | 7.05036 | 0.06795 | 0.00000
Média: | 213.3666667 | 3.531666667 | 0 | 754.1466667 | 754.155 | 59.91833333 | 1
%DPR | 0.6806933782 | 0.4877021494 | - | 0.9347995086 | 0.9348693333 | 0.1133977754 | 0

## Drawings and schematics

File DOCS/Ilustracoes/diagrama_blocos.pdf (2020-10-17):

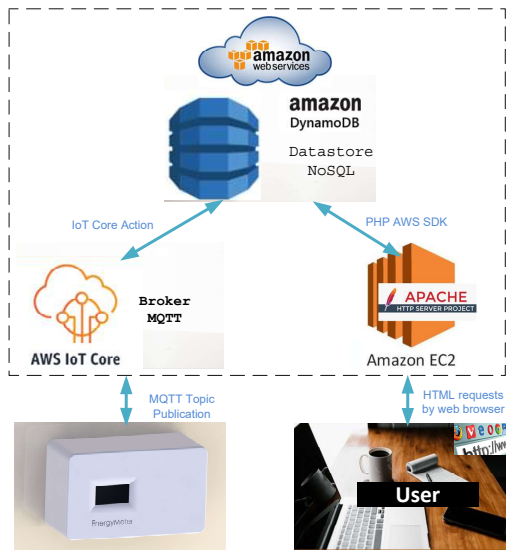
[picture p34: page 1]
User; Datastore NoSQL; Broker MQTT; IoT Core Action; PHP AWS SDK; MQTT Topic Publication

HTML requests
by web browser

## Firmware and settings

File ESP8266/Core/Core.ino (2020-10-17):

/* * Nome do arquivo: Core.h
 * Este é o arquivo main() que possui o setup e o loop principal do programa
 * 
 * Feito por Cristian Fernando Ritter
 * Para o trabalho de conclusão de curso de Engenharia Mecatrônica IfSC - Florianópolis
 * Todos os direitos reservados
 */


#include "Config.h"           // Arquivo com diversas definicoes do sketch
#include <Pinger.h>           // Biblioteca de suporte a ping
#include <ESP8266WiFi.h>      // Bibliote de suporte a wifi do módulo ESP8266
#include <SPI.h>              // Biblioteca de suporte a comunicação SPI
#include "SSD1306Wire.h"      // Bibliote de suporte ao Display OLED
//#include <PubSubClient.h>     // Biblioteca para publicacao MQTT na AWS
#include <time.h>             // Biblioteca com funções relacionadas a fuso horário
#include "funcoes_MQTT.h"     // Funcoes do autor relacionadas ao MQTT
#include "funcoes_outras.h"   // Funcoes diversas desenvolvidas pelo autor
#include "funcoes_ADE7753.h"  // funcões dos registradores ADE7753


void setup()
{
  Serial.begin(serial_speed);            // Inicia comunicação Serial.
  Serial.setDebugOutput(true);
  displayInit();                         // Inicializa displayOLED
  wifiConnect();                         // conecta a rede Wifi
  set_certifications();                  // certificações relacionadas a conta na aws
  setClock();                            // atualiza hora do sistema (para a autenticar o certificado e gerar o timestamp)
  client.setCallback(callback);          // Permite a recepção de msg pelo Tópico MQTT
  pinMode(SW_DISPLAY, INPUT);            
  pinMode(CS_PIN,OUTPUT);                
  digitalWrite(CS_PIN, HIGH);            // habilita comunicação no ADE7753 - disabled by default
  SPI.begin();                           // Inicia comunicação SPI
  configADE();                           // Configura registradores do ADE7753
}


unsigned long last_upload_time = 0;         // Uso interno nos threads
unsigned long last_debaunce_time = 0;         
unsigned long last_display_update_time = 0;   
unsigned long last_serial_print_time = 0;     

char msg_to_publish[1000];                 // Armazena a string a ser enviada para o broker
unsigned long status_register = 0;         // Armazena o valor do registrador de status do ADE
int display_current_view = 4;              // Armazena a informacao da tela apresentada no display
        

void loop() {
    if (!client.connected()) {             // Se desconectar do broker tenta reconexão
      reconnect();
    }
    client.loop();

  
    while(!statusRESET) {                  // Aguarda que o ADE esteja pronto para operar
      // this breaks when reset ends
    }

    
    retStatusRegister(&status_register);     // Atualiza status global do ADE a cada loop main

    
    if (statusWSMP(&status_register)){       //new data on wavefor
        current[0] = retV();            //volt
        current[1] = retHz();           //freq
        current[2] = retW();            //pot ativa
        current[3] = retVA();     //potencia aparente
        current[4] = retI();            //current
        current[5] = retFP();           //fat de pot  
        current[6] = retVAr();      //potencia reativa
    }

    
    if (!digitalRead(SW_DISPLAY) && threadTo(&last_debaunce_time, debaunce_time)) {      
        display_current_view++;       
        if (display_current_view == (number_of_sample_types)) { 
            display_current_view=0; 
        }
        displayUpdate(current,display_current_view);                 // Muda tela do display
    }

    
    if(threadTo(&last_display_update_time, display_update_time)) {   // Atualiza o display com as informações mais atuais
        displayUpdate(current,display_current_view);
        Serial.println(read8(CH1OS));
    }


    if(threadTo(&last_serial_print_time, time_for_serial_prints)) {     // Atualiza o display com as informações mais atuais
        imprimir_na_serial = true;
    }
  
  
    if (threadTo(&last_upload_time, time_between_uploads)) {         // Faz upload das informações mais recentes
        createMessage(msg_to_publish, current);
        publish_message(msg_to_publish); 
    }
}

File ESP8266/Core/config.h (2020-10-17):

/* * Nome do arquivo: config.h
 *  Este arquivo armazena os principais defines
 *  
 */

#define deviceid "0"   // Nome do device é armazenado na coluna id da tabela DynamoDB

#define number_of_sample_types 7                                                           // Numero de parametros
#define $sample_types {"Tensao", "Freq", "Pot_At", "Pot_Ap", "Corrente", "FP", "Pot_Re"}   // Nome dos parametros 
#define $unidades_de_medida_parametro {"V", "Hz", "W", "VA", "A", " ", "VAr"}              // Unidades de medida
#define $precisao_decimal_parametro {1, 2, 0, 0, 2, 2, 0}                                  // Casas decimais
#define time_between_uploads 30000 //ms                        // Tempo entre uploads
#define debaunce_time 250                                      // Debaunce da chave do display
#define display_update_time 1000                               // Atualizacao do display
#define time_for_serial_prints 5000                            // Intervalo de impressão na Serial

#define serial_speed 115200        // Serial port speed
#define CLOCKIN 3579545            // Clock do ADE


#define SW_DISPLAY D0              // Chave para mudança de tela
#define SDA_PIN D1                 // SPI Pin
#define SCK_PIN D2                 // SPI Pin
#define CS_PIN D8                  // SPI Pin


//WIFI
const char* ssid = "PELI";         // WiFi network name
const char* password = "peli2018"; // WiFi network password


// Configuration for NTP
const char* ntp_primary = "pool.ntp.org";     // Servidores de fuso horário
const char* ntp_secondary = "time.nist.gov";
